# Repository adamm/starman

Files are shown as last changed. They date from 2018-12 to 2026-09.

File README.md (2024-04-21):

# Starman Christmas Tree Topper

Disclaimer: This work is a *work-in-progress*.  While this project is still
under active development, version 2.1 was released _December 1st, 2022_.
What you see here is code that is largely incomplete, buggy, crashes,
and could catch fire. The PCB board is largely inefficient, expensive,
broken, and could catch fire.

Version 1 of the star is a POC I created a few years ago which was literally
a 3d-printed star with 24 LEDs hot-glued onto it, driven by a LED PWM
module from Adafruit, 3 PWM channels for audio, running from an Arduino Uno.

Version 2 is a complete redesign for 2022, including a custom PCB, 144
LEDs, 235 components, ESP32-S3 MCU, esp-idf framework, and WiFi/Bluetooth
support.  Audio is driven by 4 PWM channels, featuring a volume control and
a class-D amplifier.

Version 2.1 includes over-the-air firmware updates. I plan on releasing
new themes and songs every Holiday season. 

As of December 2023, there are **7 themes** and **81 arranged songs**.

> [!NOTE]
> I'll be demoing the Starman project, as well demoing its build process at [Calgary Maker Faire, May 4 & 5 2024](https://calgary.makerfaire.com/).
> Come talk to me if you are interested in purchasing a pre-built Starman for Christmas 2024!

You can see v2 in action here: https://www.youtube.com/watch?v=h6fquYPDars

Starman v2 Christmas Tree Star (https://www.youtube.com/watch?v=h6fquYPDars)

The PCB is created using KiCad:

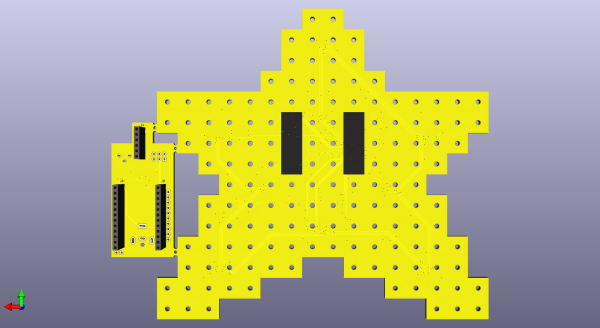
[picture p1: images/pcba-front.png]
Starman v2 PCB front

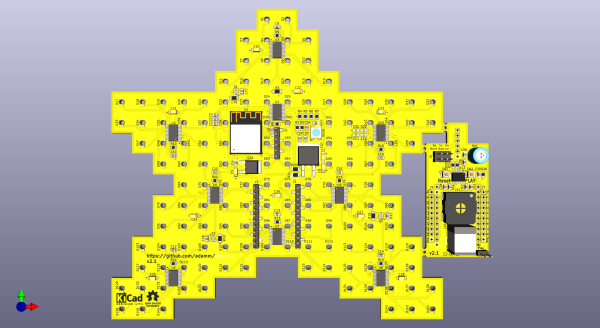
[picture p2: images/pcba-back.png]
Starman v2 PCB back


The sound module connects to the spine of the star through 20mm pin socket
risers.  Finally, a 3d-printed mount secures the display to the christmas
tree's top branch via the risers:

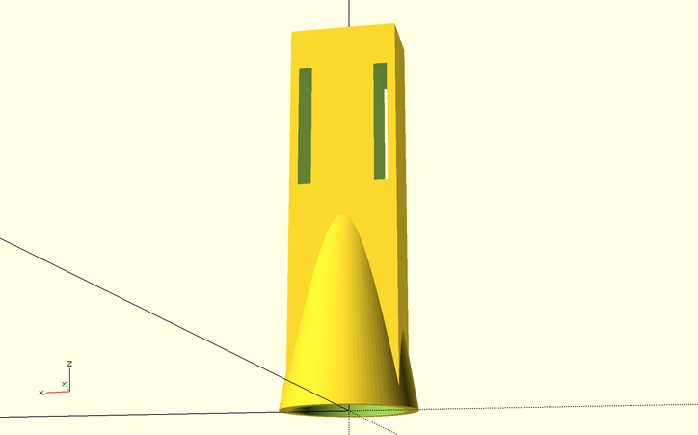
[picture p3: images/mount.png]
3D-printed mount


I plan on producing 10 units for friends and family for Christmas 2022.
Right now the costs are too high to mass produce, so perhaps sometime in
2023 I can simplify the design and cut costs for general orders.

## HOW TO PLAY

- Press the button to start the game.
- Start the game with three lives at level 1 (overworld).  If you lose all lives, it's game over.
- There is a 50% chance you will complete each level.  If you do, you move onto next level.  If not, you die and need to retry.
  - Death can occur randomly within the level.
  - Press the button again to start the next level, or retry the same level.
- There is a 40% chance you'll get a star.
  - Stars can occur randomly within the level.
  - Stars do not negate death (ie, falling into a pit).
- There is a 25% chance you'll get a 1-up, resulting in an extra life.
- If you make it to level 4 (castle) and complete it, there is a 25% chance the princess will be there and the game is over.

## Installation

1. Install Starman at the top of your tree, or on your desk, shelf, or wall.
2. Connect the play button remote cable to the play button port.  Hide the play button in your tree, desk, shelf, or wall.
3. Power it on.
4. (Optiona) Connect to your wifi network (see below) to configure the brightness and theme.
5. Press the physical play button, or press Play on the Starman web app

### Wifi Setup

1. Power on the Starman
2. Watch for a "starman_######" access point, and connect to it.
3. Search for your home Wifi, and enter the credentials
  - Starman can only connect to 2.4Ghz/WPA2 endpoints
4. Once connected, wait for your IP address to scroll past the screen
5. Open the IP address in your web browser
  - You can now use this site to play Starman directly, and to access the internal API.

If you ever want to factory reset Starman, follow this procedure:
1. Press and hold *Play* button
2. Press and release *Reset* button
3. Release *Play* button
Starman will forget about its current wifi configuration, theme, and configuration. Follow the Wifi Setup instructions above to set it back up again.

## TODO

- [X] Finalize PCB design
- [X] Play music
- [X] Implement game logic
- [X] Unique light pattern per music song/state
- [X] Flash lights in sequence with music
- [X] GPIO play button
- [X] Show simple text messages
- [X] WiFi onboarding process
- [X] Over-the-air firmware updates
- [X] WiFi play button
- [X] HTTP REST API to push text, play sound
- [X] Brightness control
- [X] Selectable themes
- [ ] Document the REST API
- [ ] Upgrade the speaker from 800mW to 1.5W for more power
- [ ] Debug the RC filter to reduce distortion

## Known Issues

- v2.1 PCB has a label that says it supports 7 to 12 volts power.  *WARNING: only 6-7V is actually supported in v2.1 hardware. __Do not connect more than 7 volts!__*
- Only 2.4Gz WPA2 wifi is supported   (Cannot connect to 5Gz or WPA Enterprise)
- Sound gets distorted at high volume levels.
- It can take a long time after startup to get an IP address and start
  the web service
- Even though wifi and the web service are online and functioning, the
  index.html sometimes takes a long time to load
- Sometimes the device spontaneously resets if wifi connection is not
  stable or strong enough
- Some songs are way too long. (>60s)
- Some songs end way too early (<3s) with a "course completed" event.

## Milestones

2022-09-01
- PCB layout identified and key components selected

2022-09-25
- Components ordered and footprints verified

2022-09-27
- Upgrade from ESP32-S2 to ESP32-S3

2022-09-29
- PCB design delivered for production

2022-10-09
- Complete migration of core game logic from Arduino version (v1) to esp-idf version (v2)

2022-10-29
- Framework for connecting to wifi / performing OTA updates

2022-11-02
- Framework for showing basic text messages, like "Game Over", "Connect to Wifi", "Firmware Update in progress", etc

2022-11-27
- Manufacturing is complete for 10 units for friends and family.

## Key Components

- ESP32-S3-Mini module

- 9x LED1642GW drivers

- 144 OSRAM LY P47 2mm LEDs

- PAM8302A amplifer

- 239 total components (35 unique)

- Translate MIDI to Playtune C array
  - https://github.com/lenshustek/miditones

## Build Dependencies

- See [BUILDING](BUILDING.md) document.

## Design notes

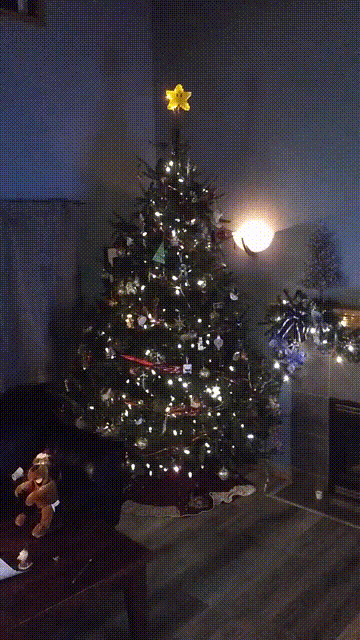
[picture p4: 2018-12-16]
images/starman-tree.gif

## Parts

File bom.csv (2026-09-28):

Refs | Value | Footprint | Qty | DNP
C1, C2, C5, C6, C40 | 10uF | Capacitor_SMD:C_0805_2012Metric,Capacitor_Tantalum_SMD:CP_EIA-3216-10_Kemet-I | 5
C3, C4, C8-C19, C35, C36, C39 | 1uF | Capacitor_SMD:C_0805_2012Metric | 17
C7, C30 | 22uF | Capacitor_SMD:C_0805_2012Metric,Capacitor_Tantalum_SMD:CP_EIA-3216-10_Kemet-I | 2
C20-C28 | 47uF | Capacitor_Tantalum_SMD:CP_EIA-3216-10_Kemet-I | 9
C29, C34 | 0.1uF | Capacitor_SMD:C_0805_2012Metric | 2
C33 | 1uF nc | Capacitor_SMD:C_0805_2012Metric | 1
C37, C38 | 220pF | Capacitor_SMD:C_0805_2012Metric | 2
D1-D144 | LED | starman:LED_Osram_Lx_P47F_D2mm_ReverseMount | 144
D145 | WS2812B nc | LED_SMD:LED_WS2812B_PLCC4_5.0x5.0mm_P3.2mm | 1
FB1, FB2 | FerriteBead | Capacitor_SMD:C_0805_2012Metric | 2
J1-J3 | M20-8771246 | Connector_PinHeader_2.54mm:PinHeader_1x06_P2.54mm_Vertical_SMD_Pin1Right,Connector_PinHeader_2.54mm:PinHeader_1x12_P2.54mm_Vertical_SMD_Pin1Right | 3
J4 | ESW-106-44-T-S | Connector_PinSocket_2.54mm:PinSocket_1x06_P2.54mm_Vertical | 1
J5 | PH2-06-UA | Connector_PinHeader_2.54mm:PinHeader_2x03_P2.54mm_Vertical | 1
J6, J8 | ESW-112-44-T-S | Connector_PinSocket_2.54mm:PinSocket_1x12_P2.54mm_Vertical | 2
J7, J9 | Conn_01x10 | Connector_PinHeader_2.54mm:PinHeader_1x10_P2.54mm_Vertical | 2
J10 | PJ-063AH | Connector_BarrelJack:BarrelJack_CUI_PJ-063AH_Horizontal | 1
J11, J12 | Conn_02x01 | Connector_PinHeader_2.54mm:PinHeader_1x02_P2.54mm_Vertical | 2
LS1 | SMS-1508MS-HT-R | starman:SPKR_SMS-1508MS-HT-R | 1
R1, R2 | 10k | Resistor_SMD:R_0805_2012Metric | 2
R3, R17-R19 | 500k | Resistor_SMD:R_1206_3216Metric | 4
R4-R7 | 75 | Resistor_SMD:R_0805_2012Metric | 4
R8-R16 | 11k | Resistor_SMD:R_0805_2012Metric | 9
R20 | 750 | Resistor_SMD:R_1206_3216Metric | 1
R21 | 250 | Resistor_SMD:R_1206_3216Metric | 1
R24, R25 | 100 | Resistor_SMD:R_0805_2012Metric | 2
R26 | 1k | Resistor_SMD:R_0805_2012Metric | 1
RV1 | 20k | Potentiometer_THT:Potentiometer_Bourns_3339P_Vertical | 1
SW1, SW2 | PTS810 SJM 250 SMTR LFS | Button_Switch_SMD:SW_SPST_PTS810 | 2
U1 | ESP32-S3-MINI-1 | Espressif:ESP32-S3-MINI-1 | 1
U2-U10 | LED1642GWTTR | Package_SO:TSSOP-24_4.4x7.8mm_P0.65mm | 9
U11 | AZ1084CS2-ADJ | Package_TO_SOT_SMD:TO-263-2 | 1
U12 | BA33BC0FP-E2 | Package_TO_SOT_SMD:TO-252-2 | 1
U13 | PAM8302AAS | Package_SO:SOP-8_3.9x4.9mm_P1.27mm | 1
X1-X3 | ECS-2333-300 | Oscillator:Oscillator_SMD_ECS_2520MV-xxx-xx-4Pin_2.5x2.0mm | 3

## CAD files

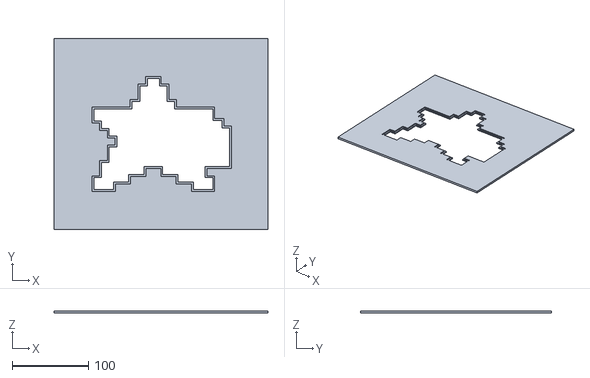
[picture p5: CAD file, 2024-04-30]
mount/stencil.stl
280.0 x 250.0 x 3.00

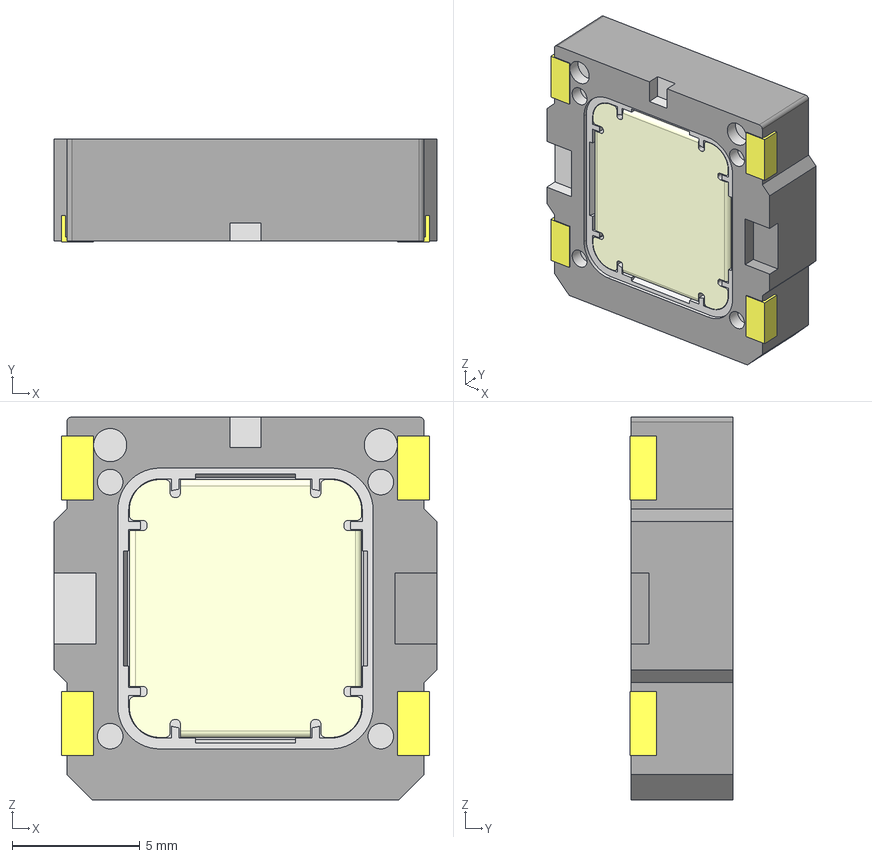
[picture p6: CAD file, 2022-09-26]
pcb/3d/SMS-1508MS-HT-R.step
15.0 x 4.05 x 15.0 mm

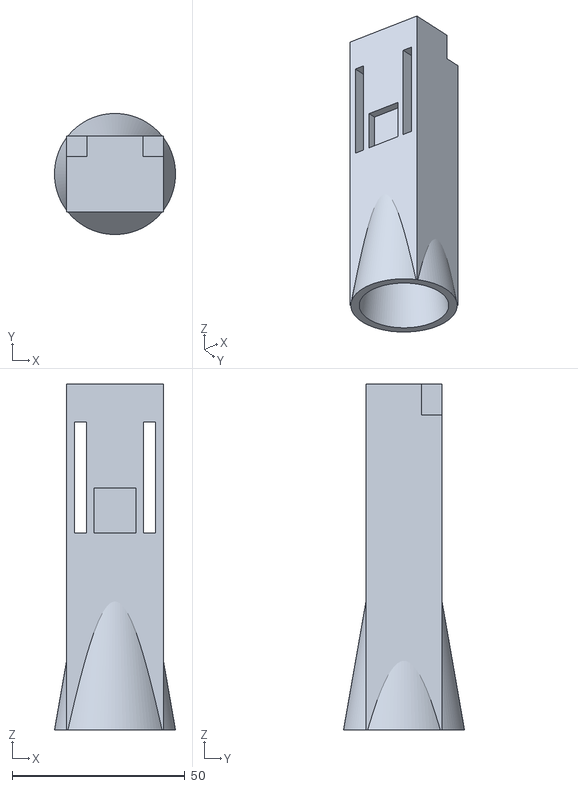
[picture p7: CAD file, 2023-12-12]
mount/mount.stl
35.0 x 35.0 x 100.0

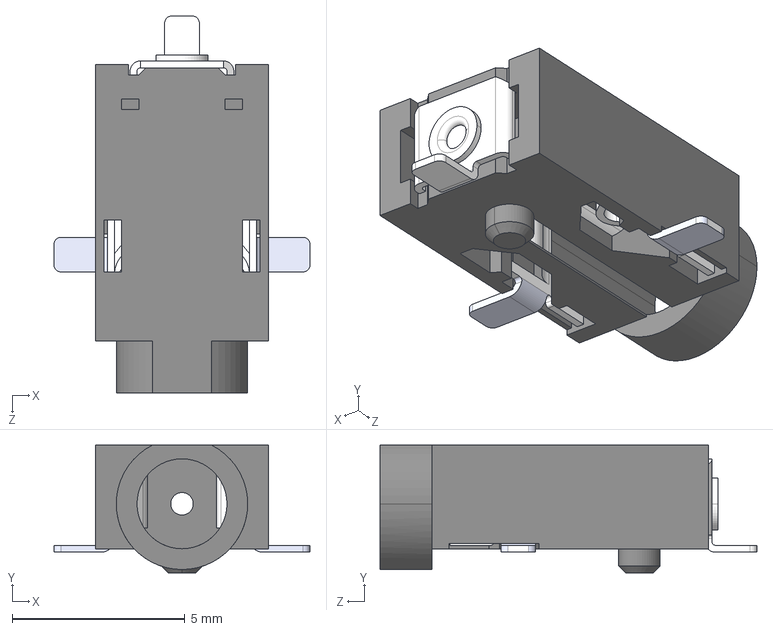
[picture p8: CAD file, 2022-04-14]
pcb/3d/CUI_DEVICES_PJ-040-SMT-TR.step
7.40 x 3.70 x 10.9 mm

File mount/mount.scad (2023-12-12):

/*
   Copyright 2022 Adam McDaniel

   Licensed under the Apache License, Version 2.0 (the "License");
   you may not use this file except in compliance with the License.
   You may obtain a copy of the License at

       http://www.apache.org/licenses/LICENSE-2.0

   Unless required by applicable law or agreed to in writing, software
   distributed under the License is distributed on an "AS IS" BASIS,
   WITHOUT WARRANTIES OR CONDITIONS OF ANY KIND, either express or implied.
   See the License for the specific language governing permissions and
   limitations under the License.
*/

body_w = 28;
body_l = 22;
body_h = 100;
body_x = -(body_w / 2);
body_y = -(body_l / 2);
body_z = 0;

// How far below the top of the body will the socket and treebranch reach?
body_socket_delta = 11;
body_treebranch_delta = 10;

socket_w = 3.5;
socket_l = body_l + 5;
socket_h = 32;

socket_left_x = -8.25 - socket_w;
socket_left_y = -(socket_l / 2);
socket_left_z = body_h - socket_h - body_socket_delta;

socket_right_x = 8.25;
socket_right_y = -(socket_l / 2);
socket_right_z = body_h - socket_h - body_socket_delta;

tree_cylinder_x = 0;
tree_cylinder_y = 0;
tree_cylinder_z = body_h - 50;
tree_cylinder_r = 7;
tree_cylinder_h = 50;

tree_cone_x = 0;
tree_cone_y = 0;
tree_cone_z = -0.01;
tree_cone_r = 7;
tree_cone_h = 60;

ldo_notch_w = 6;
ldo_notch_h = 9;
ldo_notch_l = 6;
ldo_notch_x1 = body_w/2 - ldo_notch_w + 0.1;
ldo_notch_x2 = -body_w/2 - 0.1;
ldo_notch_y = body_l/2 - ldo_notch_w + 0.1;
ldo_notch_z = body_h - ldo_notch_h + 0.1;

j10_notch_w = 12;
j10_notch_h = 13;
j10_notch_l = 3;
j10_notch_x = -j10_notch_w/2;
j10_notch_y = -body_l/2 - 0.1;
j10_notch_z = socket_left_z;

$fn = 100;

module mount_3d() {

    difference() {
        union() {
            translate([body_x, body_y, body_z])
                cube([body_w, body_l, body_h]);

            translate([tree_cone_x, tree_cone_y, tree_cone_z])
                cylinder(r=tree_cone_r, h=tree_cone_h, d1=35);
        }

        translate([socket_left_x, socket_left_y, socket_left_z])
            cube([socket_w, socket_l, socket_h]);

        translate([socket_right_x, socket_right_y, socket_right_z])
            cube([socket_w, socket_l, socket_h]);

        translate([ldo_notch_x1, ldo_notch_y, ldo_notch_z])
            cube([ldo_notch_w, ldo_notch_l, ldo_notch_h]);

        translate([ldo_notch_x2, ldo_notch_y, ldo_notch_z])
            cube([ldo_notch_w, ldo_notch_l, ldo_notch_h]);

        translate([j10_notch_x, j10_notch_y, j10_notch_z])
            cube([j10_notch_w, j10_notch_l, j10_notch_h]);

        translate([tree_cylinder_x, tree_cylinder_y, tree_cylinder_z-2])
            cylinder(r=tree_cylinder_r, h=tree_cylinder_h);

        translate([tree_cone_x, tree_cone_y, tree_cone_z-2])
            cylinder(r=tree_cone_r, h=tree_cone_h, d1=30);

    }
}


mount_3d();

// vim:syntax=c

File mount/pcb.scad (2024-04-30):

$fn = 100;
pcb_w = 151;
pcb_l = 30.5;
pcb_h = 2.2;

module pcb(draw_holes=true) {
    //translate([0, 0, -pcb_h/2])
    //difference() {
        linear_extrude(height=pcb_h) {
            // Add 0.3mm to all ends to better align with
            // 3d printer tolerance
            offset(delta=+0.3) {
                polygon(points=[
                // left side
                [0,0],[0,20],[10,20],[10,40],
                [20,40],[20,60],[30,60],[30,70],
                [20,70],[20,80],[10,80],[10,90],[0,90],
                [0,110],[50,110],[50,120],[60,120],
                [60,140],[70,140],[70,150],[90,150],
                // Top right
                [90,140],[100,140],[100,120],[110,120],
                [110,110],[160,110],
                // Expansion module
                [160,95],[172,95],[172,85],[182,85],[182,30],
                // bottom right
                [150,30],[150,20],[160,20],[160,0],
                // Bottom
                [130,0],[130,10],[110,10],[110,20],
                [90,20],[90,30],[70,30],[70,20],[50,20],
                [50,10],[30,10],[30,0]]);
            }
        }
    //}
}

//rotate([90, 0, 90]) {
//    union() {
//        pcb(true);
//    }
//}

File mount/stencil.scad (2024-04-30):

include <pcb.scad>;


board_w = 280;
board_h = 3.0;
board_l = 250;
board_x = -50;
board_y = -50;
board_z = 0.01;

stencil_w = 240;
stencil_h = 3;
stencil_l = 210;
stencil_x = -30;
stencil_y = -30;
stencil_z = 3;

module negative_pcb(x, y, z) {
    translate([x, y, z+1.4])
        pcb(false);
    translate([x, y, z])
        linear_extrude(height=board_h+4)
            offset(delta=-2.5)
                projection(cut=true)
                    pcb(false);
}

module board() {
    difference() {
        translate([board_x, board_y, board_z])
            cube([board_w, board_l, board_h]);
        //translate([stencil_x, stencil_y, stencil_z])
            //cube([stencil_w, stencil_l, stencil_h]);
        negative_pcb(0, 0, 0);
    }
}

board();

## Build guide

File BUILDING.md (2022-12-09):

# BUILDING

This doc describes building the source code, not building your own Starman :)
Except for Step 1, the instructions here are not specific to Starman and can be
used for any "esp-idf"-based project.

> While the Starman hardware is Arduino-compabile, the codebase is not written
> using the Arduino toolchain.  If you want to use the hardware as an arbitrary
> Arduino device, feel free, but to access the lights and sound you'll have to
> write your own port :)

## 1. Solder 2x3 headers onto J5

The back module pops off, but it's pretty stiff.  Take care not to damage any
of the components.  This will allow you access to the back to solder on the
headers, if they're not there already.

## 2. Get an [ESP-Prog](https://espressif-docs.readthedocs-hosted.com/projects/espressif-esp-iot-solution/en/latest/hw-reference/ESP-Prog_guide.html) and cables to connect to J5

Be sure to match up pins with the ESP-Prog's 2x3
[communication interface](https://espressif-docs.readthedocs-hosted.com/projects/espressif-esp-iot-solution/en/latest/hw-reference/ESP-Prog_guide.html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).
A ribbon cable [like this one](https://www.amazon.ca/CablesOnline-12-inch-2-54mm-Pitch-Female-FR-0612/dp/B078LM31J9)
is most convenient.

Alternatively, you can get away with not using an ESP-Prog and instead use any
FTDI USB->Serial adapter, [like this one](https://www.sparkfun.com/products/9717),
just be sure it's 3.3V logic level.  Also, you won't have convenient access to
trigger the boot and reset pins automatically.  You'll have to manually touch
those to ground to reset into bootloader mode and upload new code.

Be sure to only connect your cable to the TX, RX, and Gnd pins on J5.  The
transmit/receive is relative to the Starman MCU, so you may need to
connect the TX pin to your cable's RX port, and vice versa.

## 3. [Download and install the FDTI driver](https://ftdichip.com/drivers/vcp-drivers/)

If you have an ESP-Prog or other FTDI USB->Serial device or cable, download
and install the FTDI drivers [here](https://ftdichip.com/drivers/vcp-drivers/).
If you have a non-FTDI USB->Serial device, you'll need to follow its instructions.

## 4. [Download and install the esp-idf toolchain](https://docs.espressif.com/projects/esp-idf/en/latest/esp32/get-started/index.html#installation)

## 5. Clone this repository

The codebase lives in the main/ directory, but be sure to run all the
following commands in the root of the cloned repository.

## 6. Build, Flash, Monitor the project

If you're using an IDE with the [Eclipse plugin](https://github.com/espressif/idf-eclipse-plugin/blob/master/README.md)
or [VSCode extension](https://github.com/espressif/vscode-esp-idf-extension/blob/master/docs/tutorial/install.md),
follow those instructions.  If you using the command-line follow these steps frim the firmware/ directory:

1. `idf.py set-target esp32s3` to prepare the build environment.  (You only need to do this once.)

2. `idf.py build` to compile the project.

3. `idf.py flash` to actually upload the compiled binary.

To upload your code you need to be in bootloader mode.  The ESP-Prog will
take care of this for you, but if you used your own cable or FTDI device,
you'll have to manually enter bootloader mode.  To do this, connect J5
"Boot" pin to "Gnd", press the Reset button, then disconnect the "Boot" pin.
Run `idf.py flash` normally.  After flashing is complete you need to press
"Reset" again for normal operations.

4. `idf.py monitor` to open up a serial port to monitor the logs of the device.

You can combine all three steps into one command `idf.py build flash monitor`
for convenience.

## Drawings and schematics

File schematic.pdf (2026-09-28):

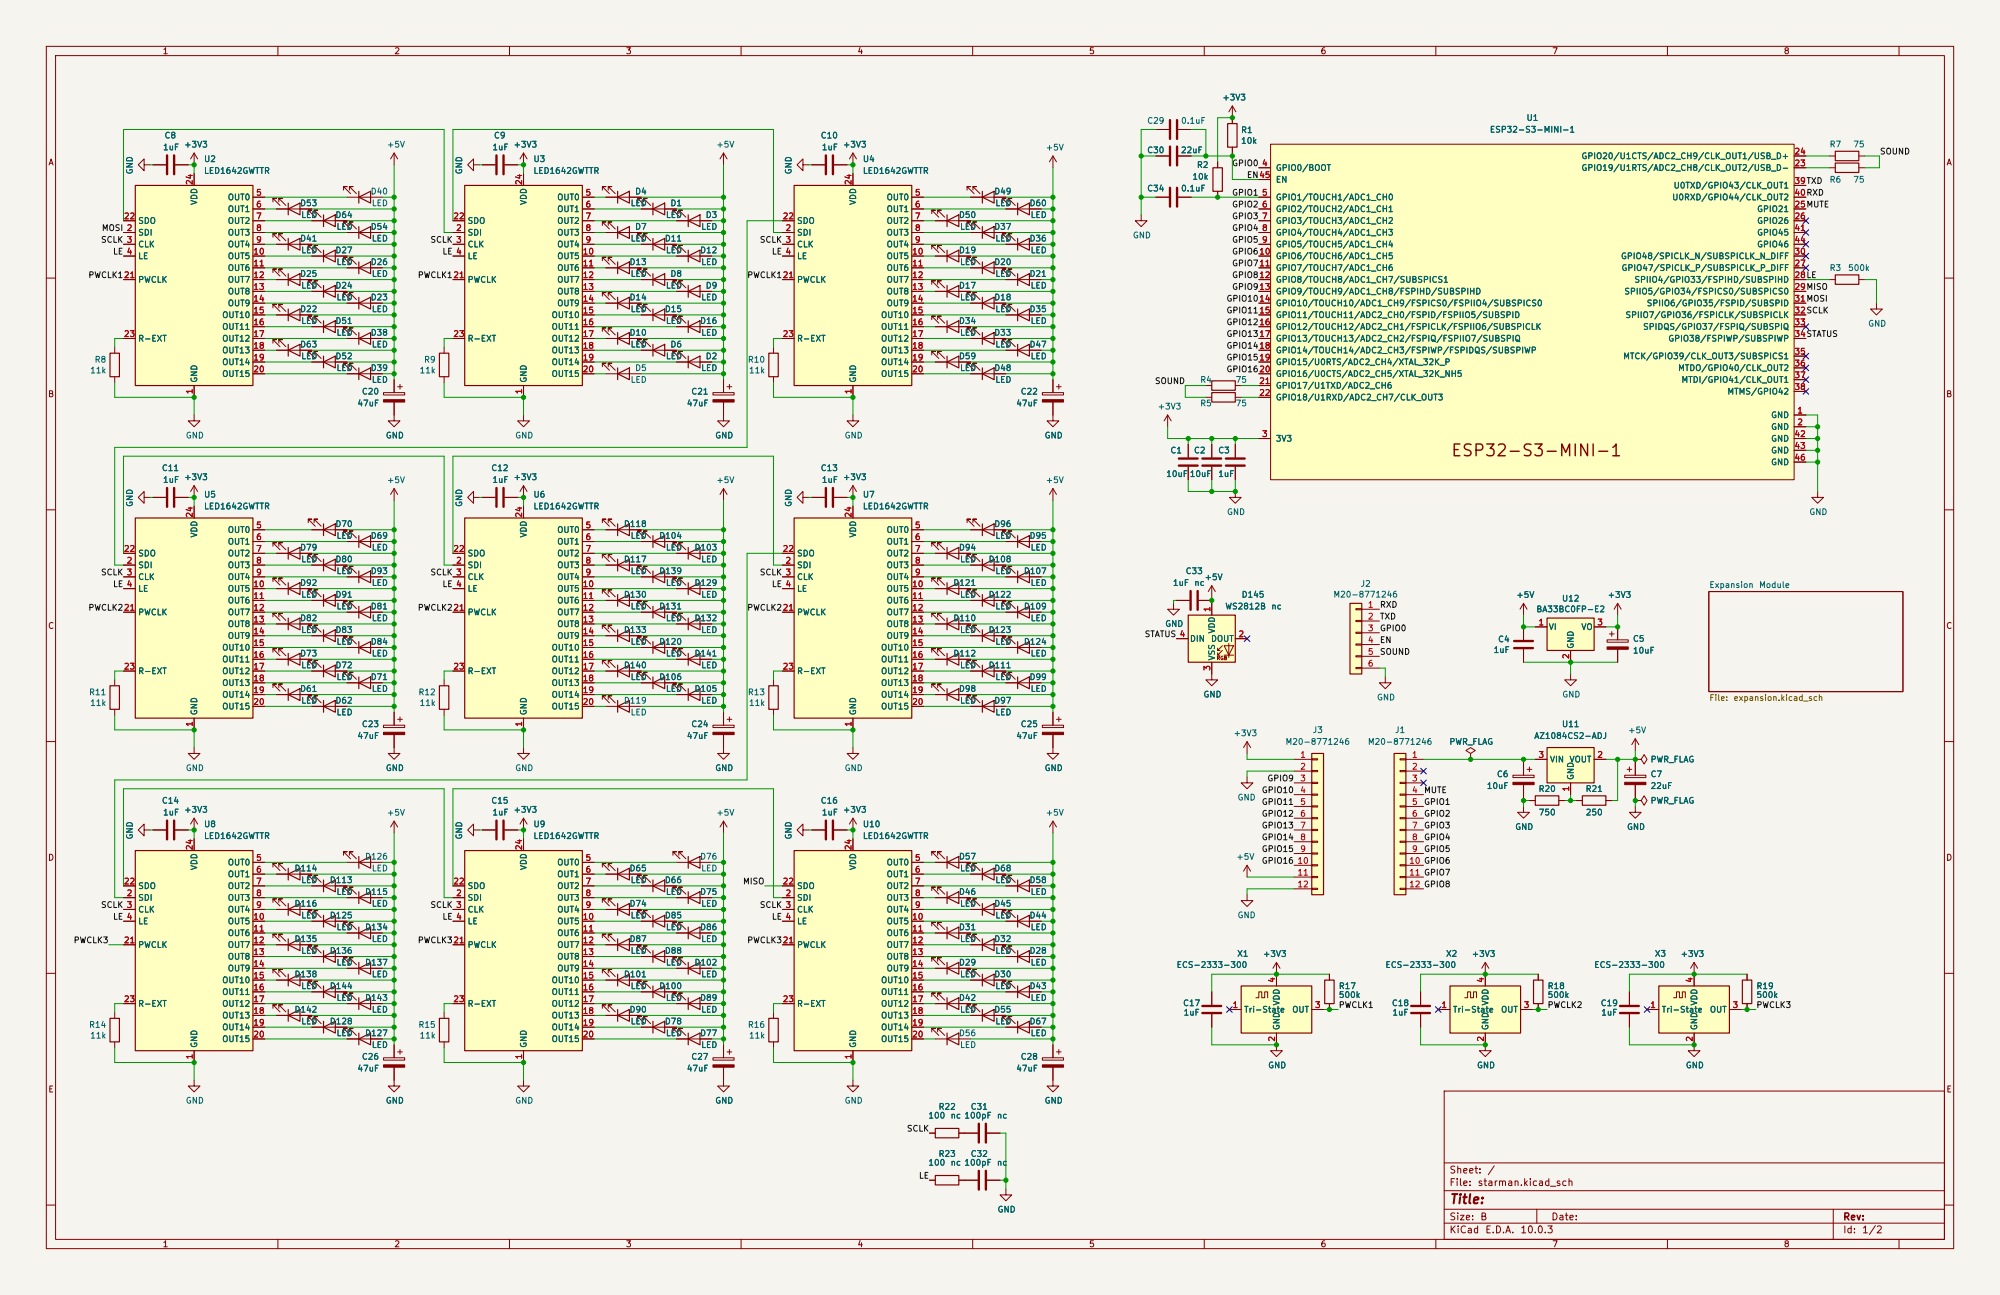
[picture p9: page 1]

SOUND MISO MOSI STATUS

Size: B | Rev:
KiCad E.D.A. 10.0.3 | Id: 1/2

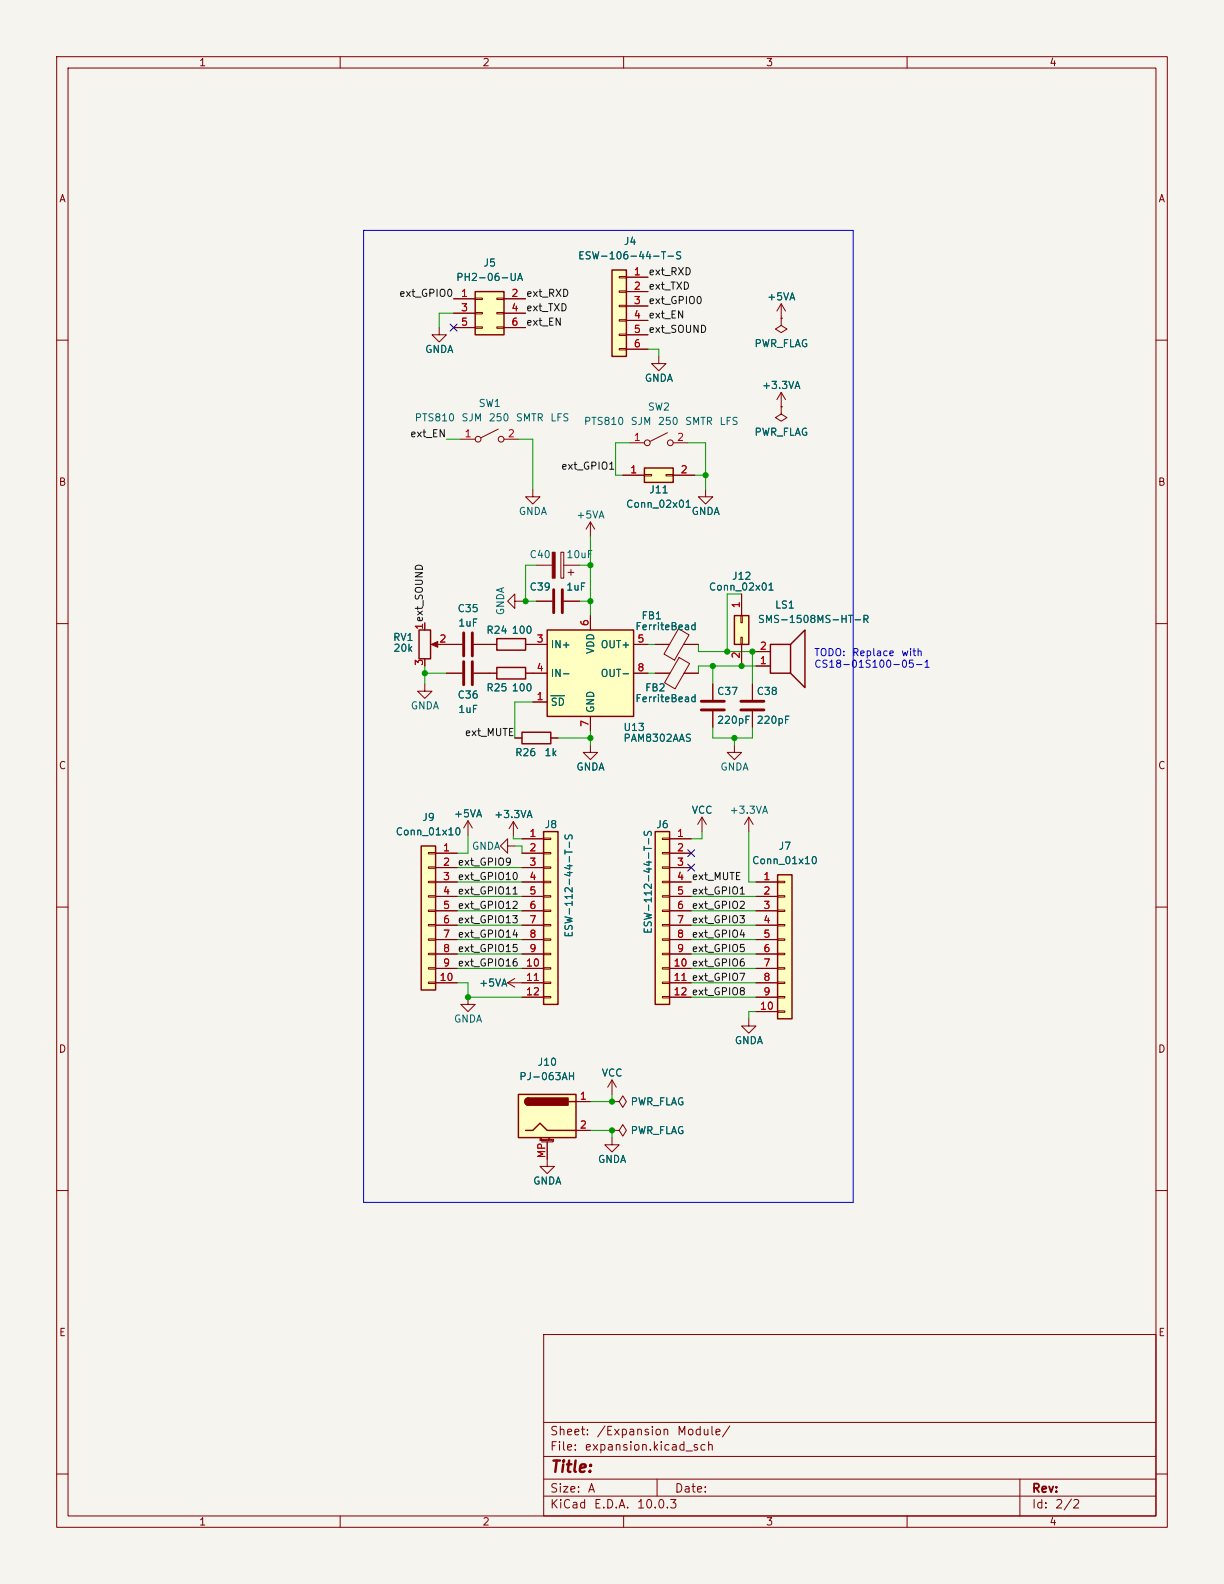
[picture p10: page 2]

Size: A | Rev:
KiCad E.D.A. 10.0.3 | Id: 2/2

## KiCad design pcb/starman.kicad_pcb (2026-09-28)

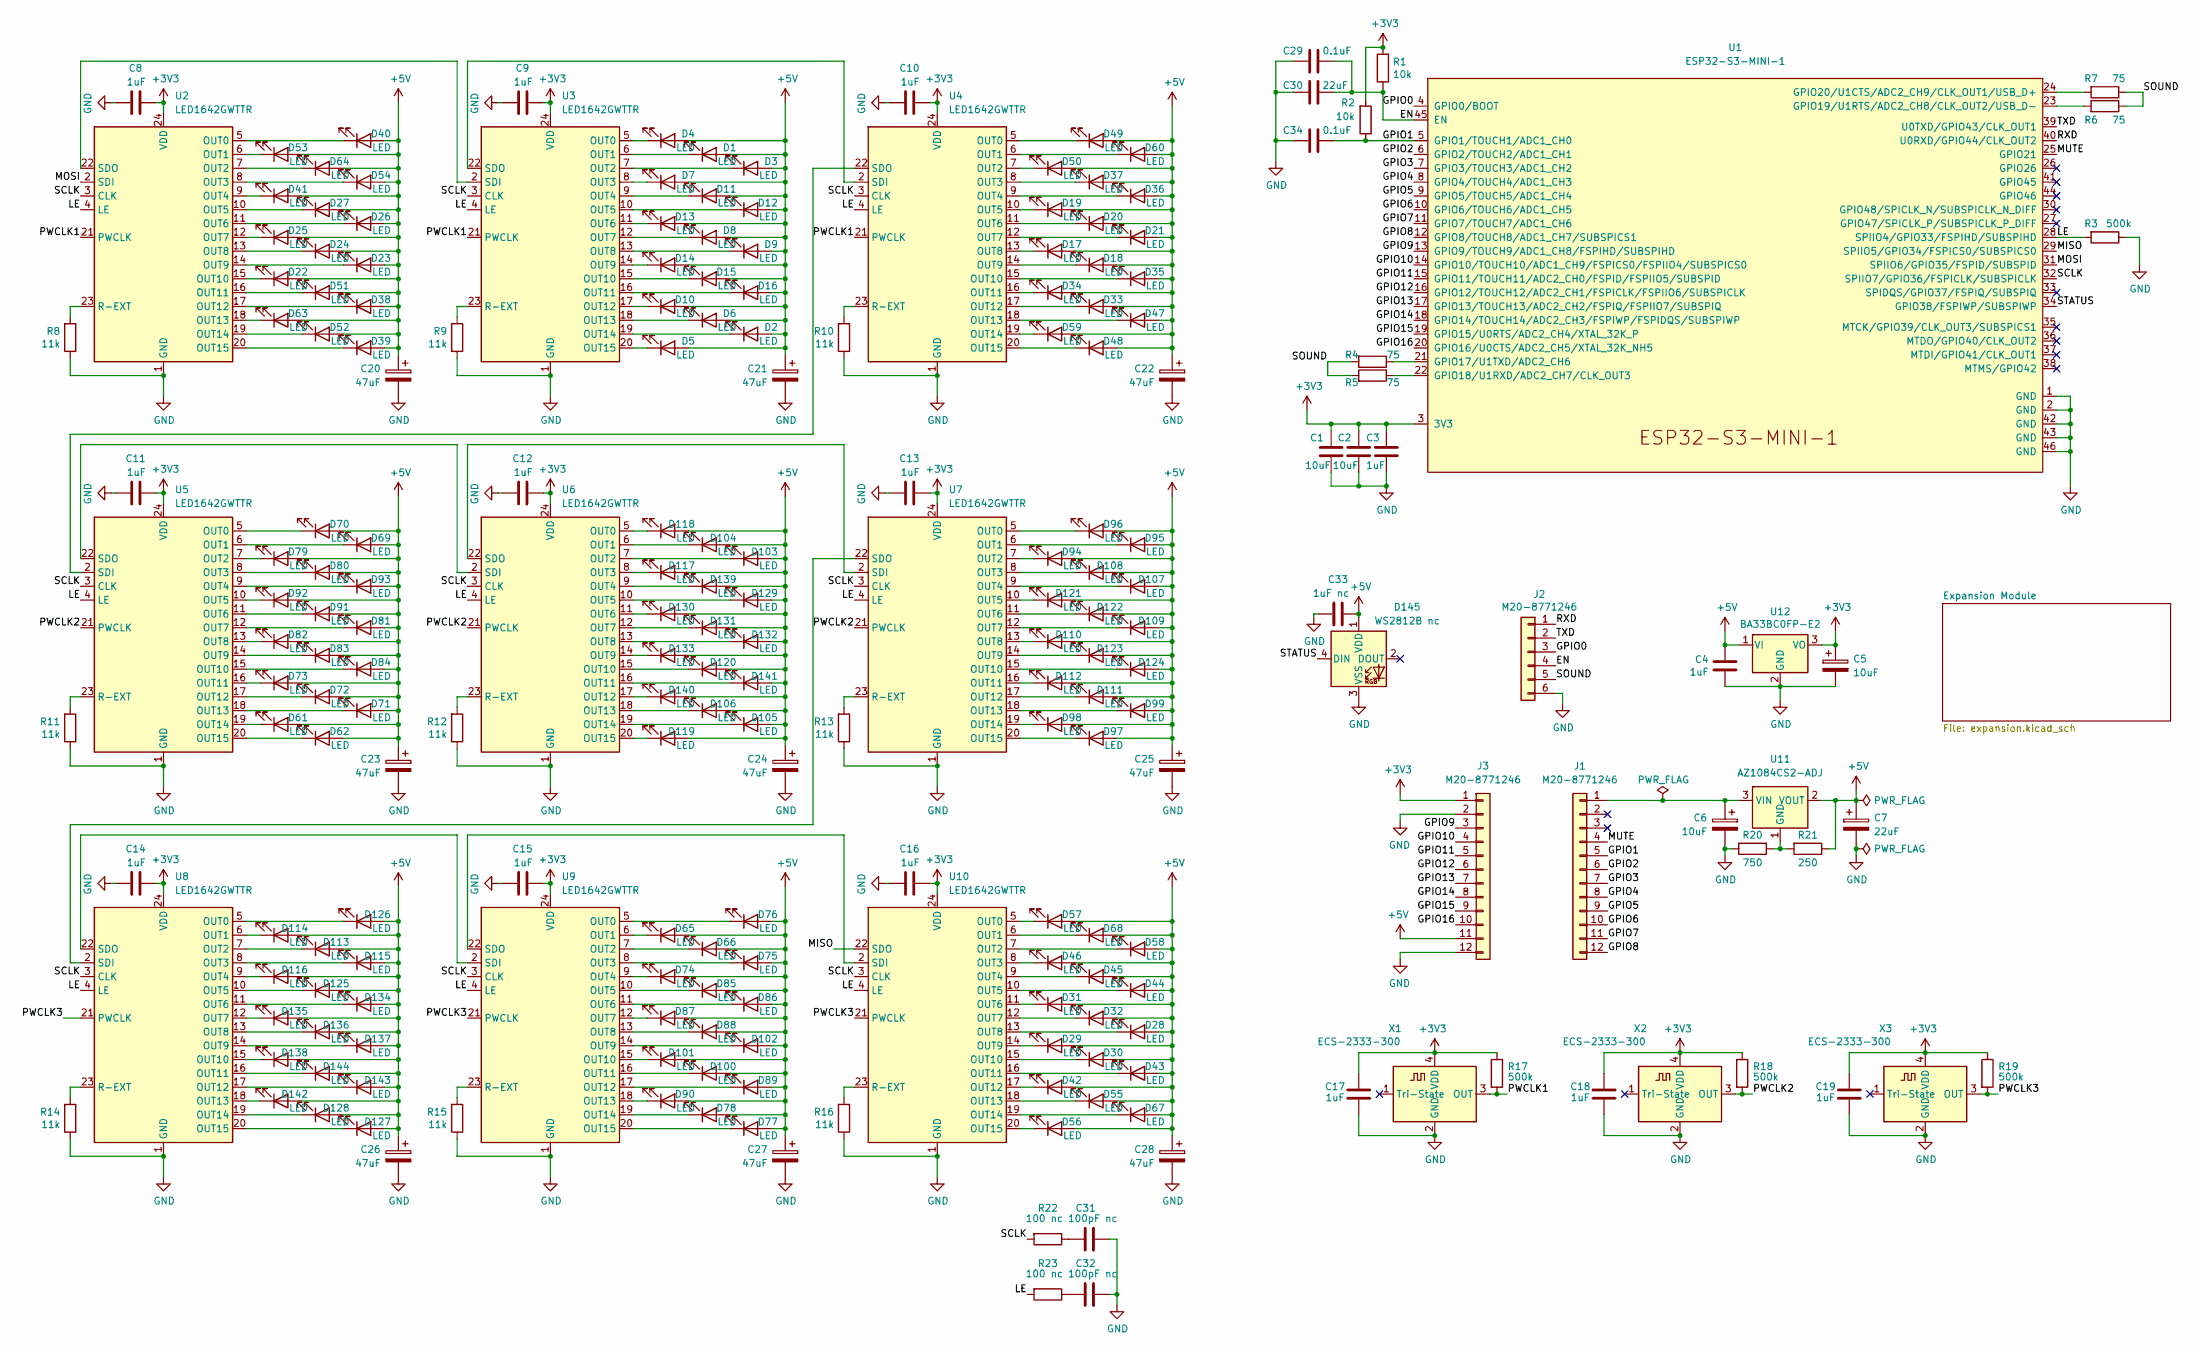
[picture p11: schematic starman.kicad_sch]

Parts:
C1, C2: 10uF; C_0805_2012Metric
C3, C4, C8, C9, C10, C11, C12, C13, C14, C15, C16, C17, C18, C19: 1uF; C_0805_2012Metric
C5, C6: 10uF; CP_EIA-3216-10_Kemet-I
C7: 22uF; CP_EIA-3216-10_Kemet-I
C20, C21, C22, C23, C24, C25, C26, C27, C28: 47uF; CP_EIA-3216-10_Kemet-I
C29, C34: 0.1uF; C_0805_2012Metric
C30: 22uF; C_0805_2012Metric
C31, C32: 100pF nc; C_0805_2012Metric
C33: 1uF nc; C_0805_2012Metric
D1, D2, D3, D4, D5, D6, D7, D8, D9, D10, D11, D12, D13, D14, D15, D16, D17, D18, D19, D20, D21, D22, D23, D24, D25, D26, D27, D28, D29, D30, D31, D32, D33, D34, D35, D36, D37, D38, D39, D40, D41, D42, D43, D44, D45, D46, D47, D48, D49, D50, D51, D52, D53, D54, D55, D56, D57, D58, D59, D60, D61, D62, D63, D64, D65, D66, D67, D68, D69, D70, D71, D72, D73, D74, D75, D76, D77, D78, D79, D80, D81, D82, D83, D84, D85, D86, D87, D88, D89, D90, D91, D92, D93, D94, D95, D96, D97, D98, D99, D100, D101, D102, D103, D104, D105, D106, D107, D108, D109, D110, D111, D112, D113, D114, D115, D116, D117, D118, D119, D120, D121, D122, D123, D124, D125, D126, D127, D128, D129, D130, D131, D132, D133, D134, D135, D136, D137, D138, D139, D140, D141, D142, D143, D144: LED; LED_Osram_Lx_P47F_D2mm_ReverseMount
D145: WS2812B nc; LED_WS2812B_PLCC4_5.0x5.0mm_P3.2mm
J1, J3: M20-8771246; PinHeader_1x12_P2.54mm_Vertical_SMD_Pin1Right
J2: M20-8771246; PinHeader_1x06_P2.54mm_Vertical_SMD_Pin1Right
R1, R2: 10k; R_0805_2012Metric
R3, R17, R18, R19: 500k; R_1206_3216Metric
R4, R5, R6, R7: 75; R_0805_2012Metric
R8, R9, R10, R11, R12, R13, R14, R15, R16: 11k; R_0805_2012Metric
R20: 750; R_1206_3216Metric
R21: 250; R_1206_3216Metric
R22, R23: 100 nc; R_0805_2012Metric
U1: ESP32-S3-MINI-1
U2, U3, U4, U5, U6, U7, U8, U9, U10: LED1642GWTTR; TSSOP-24_4.4x7.8mm_P0.65mm
U11: AZ1084CS2-ADJ; TO-263-2
U12: BA33BC0FP-E2; TO-252-2
X1, X2, X3: ECS-2333-300; Oscillator_SMD_ECS_2520MV-xxx-xx-4Pin_2.5x2.0mm

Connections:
+3V3: C1.2, C2.2, C3.2, C5.1, C8.1, C9.1, C10.1, C11.1, C12.1, C13.1, C14.1, C15.1, C16.1, C17.2, C18.2, C19.2, J3.1, R1.2, R2.2, R17.1, R18.1, R19.1, U1.3 (3V3), U2.24 (VDD), U3.24 (VDD), U4.24 (VDD), U5.24 (VDD), U6.24 (VDD), U7.24 (VDD), U8.24 (VDD), U9.24 (VDD), U10.24 (VDD), U12.3 (VO), X1.4 (VDD), X2.4 (VDD), X3.4 (VDD)
+5V: C4.2, C7.1, C20.1, C21.1, C22.1, C23.1, C24.1, C25.1, C26.1, C27.1, C28.1, C33.1, D1.2 (A), D2.2 (A), D3.2 (A), D4.2 (A), D5.2 (A), D6.2 (A), D7.2 (A), D8.2 (A), D9.2 (A), D10.2 (A), D11.2 (A), D12.2 (A), D13.2 (A), D14.2 (A), D15.2 (A), D16.2 (A), D17.2 (A), D18.2 (A), D19.2 (A), D20.2 (A), D21.2 (A), D22.2 (A), D23.2 (A), D24.2 (A), D25.2 (A), D26.2 (A), D27.2 (A), D28.2 (A), D29.2 (A), D30.2 (A), D31.2 (A), D32.2 (A), D33.2 (A), D34.2 (A), D35.2 (A), D36.2 (A), D37.2 (A), D38.2 (A), D39.2 (A), D40.2 (A), D41.2 (A), D42.2 (A), D43.2 (A), D44.2 (A), D45.2 (A), D46.2 (A), D47.2 (A), D48.2 (A), D49.2 (A), D50.2 (A), D51.2 (A), D52.2 (A), D53.2 (A), D54.2 (A), D55.2 (A), D56.2 (A), D57.2 (A), D58.2 (A), D59.2 (A), D60.2 (A), D61.2 (A), D62.2 (A), D63.2 (A), D64.2 (A), D65.2 (A), D66.2 (A), D67.2 (A), D68.2 (A), D69.2 (A), D70.2 (A), D71.2 (A), D72.2 (A), D73.2 (A), D74.2 (A), D75.2 (A), D76.2 (A), D77.2 (A), D78.2 (A), D79.2 (A), D80.2 (A), D81.2 (A), D82.2 (A), D83.2 (A), D84.2 (A), D85.2 (A), D86.2 (A), D87.2 (A), D88.2 (A), D89.2 (A), D90.2 (A), D91.2 (A), D92.2 (A), D93.2 (A), D94.2 (A), D95.2 (A), D96.2 (A), D97.2 (A), D98.2 (A), D99.2 (A), D100.2 (A), D101.2 (A), D102.2 (A), D103.2 (A), D104.2 (A), D105.2 (A), D106.2 (A), D107.2 (A), D108.2 (A), D109.2 (A), D110.2 (A), D111.2 (A), D112.2 (A), D113.2 (A), D114.2 (A), D115.2 (A), D116.2 (A), D117.2 (A), D118.2 (A), D119.2 (A), D120.2 (A), D121.2 (A), D122.2 (A), D123.2 (A), D124.2 (A), D125.2 (A), D126.2 (A), D127.2 (A), D128.2 (A), D129.2 (A), D130.2 (A), D131.2 (A), D132.2 (A), D133.2 (A), D134.2 (A), D135.2 (A), D136.2 (A), D137.2 (A), D138.2 (A), D139.2 (A), D140.2 (A), D141.2 (A), D142.2 (A), D143.2 (A), D144.2 (A), D145.1 (VDD), J3.11, R21.1, U11.2 (VOUT), U12.1 (VI)
/EN: C29.1, C30.1, J2.4, R1.1, U1.45 (EN)
/GPIO0: J2.3, U1.4 (GPIO0/BOOT)
/GPIO1: C34.1, J1.5, R2.1, U1.5 (GPIO1/TOUCH1/ADC1_CH0)
/GPIO2: J1.6, U1.6 (GPIO2/TOUCH2/ADC1_CH1)
/GPIO3: J1.7, U1.7 (GPIO3/TOUCH3/ADC1_CH2)
/GPIO4: J1.8, U1.8 (GPIO4/TOUCH4/ADC1_CH3)
/GPIO5: J1.9, U1.9 (GPIO5/TOUCH5/ADC1_CH4)
/GPIO6: J1.10, U1.10 (GPIO6/TOUCH6/ADC1_CH5)
/GPIO7: J1.11, U1.11 (GPIO7/TOUCH7/ADC1_CH6)
/GPIO8: J1.12, U1.12 (GPIO8/TOUCH8/ADC1_CH7/SUBSPICS1)
/GPIO9: J3.3, U1.13 (GPIO9/TOUCH9/ADC1_CH8/FSPIHD/SUBSPIHD)
/GPIO10: J3.4, U1.14 (GPIO10/TOUCH10/ADC1_CH9/FSPICS0/FSPIIO4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)
/GPIO11: J3.5, U1.15 (GPIO11/TOUCH11/ADC2_CH0/FSPID/FSPIIO5/S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)
/GPIO12: J3.6, U1.16 (GPIO12/TOUCH12/ADC2_CH1/FSPICLK/FSPIIO6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)
/GPIO13: J3.7, U1.17 (GPIO13/TOUCH13/ADC2_CH2/FSPIQ/FSPIIO7/S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)
/GPIO14: J3.8, U1.18 (GPIO14/TOUCH14/ADC2_CH3/FSPIWP/FSPIDQS/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)
/GPIO15: J3.9, U1.19 (GPIO15/U0RTS/ADC2_CH4/XTAL_32K_P)
/GPIO16: J3.10, U1.20 (GPIO16/U0CTS/ADC2_CH5/XTAL_32K_NH5)
/LE: R3.2, R23.2, U1.28 (SPIIO4/GPIO33/FSPIHD/SUBSPIHD), U2.4 (LE), U3.4 (LE), U4.4 (LE), U5.4 (LE), U6.4 (LE), U7.4 (LE), U8.4 (LE), U9.4 (LE), U10.4 (LE)
/MISO: U1.29 (SPIIO5/GPIO34/FSPICS0/SUBSPICS0), U10.22 (SDO)
/MOSI: U1.31 (SPIIO6/GPIO35/FSPID/SUBSPID), U2.2 (SDI)
/MUTE: J1.4, U1.25 (GPIO21)
/PWCLK1: R17.2, U2.21 (PWCLK), U3.21 (PWCLK), U4.21 (PWCLK), X1.3 (OUT)
/PWCLK2: R18.2, U5.21 (PWCLK), U6.21 (PWCLK), U7.21 (PWCLK), X2.3 (OUT)
/PWCLK3: R19.2, U8.21 (PWCLK), U9.21 (PWCLK), U10.21 (PWCLK), X3.3 (OUT)
/RXD: J2.1, U1.40 (U0RXD/GPIO44/CLK_OUT2)
/SCLK: R22.2, U1.32 (SPIIO7/GPIO36/FSPICLK/SUBSPICLK), U2.3 (CLK), U3.3 (CLK), U4.3 (CLK), U5.3 (CLK), U6.3 (CLK), U7.3 (CLK), U8.3 (CLK), U9.3 (CLK), U10.3 (CLK)
/SOUND: J2.5, R4.2, R5.2, R6.1, R7.1
/STATUS: D145.4 (DIN), U1.34 (GPIO38/FSPIWP/SUBSPIWP)
/TXD: J2.2, U1.39 (U0TXD/GPIO43/CLK_OUT1)
GND: C1.1, C2.1, C3.1, C4.1, C5.2, C6.2, C7.2, C8.2, C9.2, C10.2, C11.2, C12.2, C13.2, C14.2, C15.2, C16.2, C17.1, C18.1, C19.1, C20.2, C21.2, C22.2, C23.2, C24.2, C25.2, C26.2, C27.2, C28.2, C29.2, C30.2, C31.1, C32.1, C33.2, C34.2, D145.3 (VSS), J2.6, J3.2, J3.12, R3.1, R8.1, R9.1, R10.1, R11.1, R12.1, R13.1, R14.1, R15.1, R16.1, R20.2, U1.1 (GND), U1.2 (GND), U1.42 (GND), U1.43 (GND), U1.46 (GND), U2.1 (GND), U3.1 (GND), U4.1 (GND), U5.1 (GND), U6.1 (GND), U7.1 (GND), U8.1 (GND), U9.1 (GND), U10.1 (GND), U12.2 (GND), X1.2 (GND), X2.2 (GND), X3.2 (GND)
unnamed: C6.1, J1.1, U11.3 (VIN)
unnamed: C31.2, R22.1
unnamed: C32.2, R23.1
unnamed: D1.1 (K), U3.6 (OUT1)
unnamed: D2.1 (K), U3.19 (OUT14)
unnamed: D3.1 (K), U3.7 (OUT2)
unnamed: D4.1 (K), U3.5 (OUT0)
unnamed: D5.1 (K), U3.20 (OUT15)
unnamed: D6.1 (K), U3.18 (OUT13)
unnamed: D7.1 (K), U3.8 (OUT3)
unnamed: D8.1 (K), U3.12 (OUT7)
unnamed: D9.1 (K), U3.13 (OUT8)
unnamed: D10.1 (K), U3.17 (OUT12)
unnamed: D11.1 (K), U3.9 (OUT4)
unnamed: D12.1 (K), U3.10 (OUT5)
unnamed: D13.1 (K), U3.11 (OUT6)
unnamed: D14.1 (K), U3.14 (OUT9)
unnamed: D15.1 (K), U3.15 (OUT10)
unnamed: D16.1 (K), U3.16 (OUT11)
unnamed: D17.1 (K), U4.13 (OUT8)
unnamed: D18.1 (K), U4.14 (OUT9)
unnamed: D19.1 (K), U4.10 (OUT5)
unnamed: D20.1 (K), U4.11 (OUT6)
unnamed: D21.1 (K), U4.12 (OUT7)
unnamed: D22.1 (K), U2.15 (OUT10)
unnamed: D23.1 (K), U2.14 (OUT9)
unnamed: D24.1 (K), U2.13 (OUT8)
unnamed: D25.1 (K), U2.12 (OUT7)
unnamed: D26.1 (K), U2.11 (OUT6)
unnamed: D27.1 (K), U2.10 (OUT5)
unnamed: D28.1 (K), U10.13 (OUT8)
unnamed: D29.1 (K), U10.14 (OUT9)
unnamed: D30.1 (K), U10.15 (OUT10)
unnamed: D31.1 (K), U10.11 (OUT6)
unnamed: D32.1 (K), U10.12 (OUT7)
unnamed: D33.1 (K), U4.17 (OUT12)
unnamed: D34.1 (K), U4.16 (OUT11)
unnamed: D35.1 (K), U4.15 (OUT10)
unnamed: D36.1 (K), U4.9 (OUT4)
unnamed: D37.1 (K), U4.8 (OUT3)
unnamed: D38.1 (K), U2.17 (OUT12)
unnamed: D39.1 (K), U2.20 (OUT15)
unnamed: D40.1 (K), U2.5 (OUT0)
unnamed: D41.1 (K), U2.9 (OUT4)
unnamed: D42.1 (K), U10.17 (OUT12)
unnamed: D43.1 (K), U10.16 (OUT11)
unnamed: D44.1 (K), U10.10 (OUT5)
unnamed: D45.1 (K), U10.9 (OUT4)
unnamed: D46.1 (K), U10.8 (OUT3)
unnamed: D47.1 (K), U4.18 (OUT13)
unnamed: D48.1 (K), U4.20 (OUT15)
unnamed: D49.1 (K), U4.5 (OUT0)
unnamed: D50.1 (K), U4.7 (OUT2)
unnamed: D51.1 (K), U2.16 (OUT11)
unnamed: D52.1 (K), U2.19 (OUT14)
unnamed: D53.1 (K), U2.6 (OUT1)
unnamed: D54.1 (K), U2.8 (OUT3)
unnamed: D55.1 (K), U10.18 (OUT13)
unnamed: D56.1 (K), U10.20 (OUT15)
unnamed: D57.1 (K), U10.5 (OUT0)
unnamed: D58.1 (K), U10.7 (OUT2)
unnamed: D59.1 (K), U4.19 (OUT14)
unnamed: D60.1 (K), U4.6 (OUT1)
unnamed: D61.1 (K), U5.19 (OUT14)
unnamed: D62.1 (K), U5.20 (OUT15)
unnamed: D63.1 (K), U2.18 (OUT13)
unnamed: D64.1 (K), U2.7 (OUT2)
unnamed: D65.1 (K), U9.6 (OUT1)
unnamed: D66.1 (K), U9.7 (OUT2)
unnamed: D67.1 (K), U10.19 (OUT14)
unnamed: D68.1 (K), U10.6 (OUT1)
unnamed: D69.1 (K), U5.6 (OUT1)
unnamed: D70.1 (K), U5.5 (OUT0)
unnamed: D71.1 (K), U5.18 (OUT13)
unnamed: D72.1 (K), U5.17 (OUT12)
unnamed: D73.1 (K), U5.16 (OUT11)
unnamed: D74.1 (K), U9.9 (OUT4)
unnamed: D75.1 (K), U9.8 (OUT3)
unnamed: D76.1 (K), U9.5 (OUT0)
unnamed: D77.1 (K), U9.20 (OUT15)
unnamed: D78.1 (K), U9.19 (OUT14)
unnamed: D79.1 (K), U5.7 (OUT2)
unnamed: D80.1 (K), U5.8 (OUT3)
unnamed: D81.1 (K), U5.12 (OUT7)
unnamed: D82.1 (K), U5.13 (OUT8)
unnamed: D83.1 (K), U5.14 (OUT9)
unnamed: D84.1 (K), U5.15 (OUT10)
unnamed: D85.1 (K), U9.10 (OUT5)
unnamed: D86.1 (K), U9.11 (OUT6)
unnamed: D87.1 (K), U9.12 (OUT7)
unnamed: D88.1 (K), U9.13 (OUT8)
unnamed: D89.1 (K), U9.17 (OUT12)
unnamed: D90.1 (K), U9.18 (OUT13)
unnamed: D91.1 (K), U5.11 (OUT6)
unnamed: D92.1 (K), U5.10 (OUT5)
unnamed: D93.1 (K), U5.9 (OUT4)
unnamed: D94.1 (K), U7.7 (OUT2)
unnamed: D95.1 (K), U7.6 (OUT1)
unnamed: D96.1 (K), U7.5 (OUT0)
unnamed: D97.1 (K), U7.20 (OUT15)
unnamed: D98.1 (K), U7.19 (OUT14)
unnamed: D99.1 (K), U7.18 (OUT13)
unnamed: D100.1 (K), U9.16 (OUT11)
unnamed: D101.1 (K), U9.15 (OUT10)
unnamed: D102.1 (K), U9.14 (OUT9)
unnamed: D103.1 (K), U6.7 (OUT2)
unnamed: D104.1 (K), U6.6 (OUT1)
unnamed: D105.1 (K), U6.19 (OUT14)
unnamed: D106.1 (K), U6.18 (OUT13)
unnamed: D107.1 (K), U7.9 (OUT4)
unnamed: D108.1 (K), U7.8 (OUT3)
unnamed: D109.1 (K), U7.12 (OUT7)
unnamed: D110.1 (K), U7.13 (OUT8)
unnamed: D111.1 (K), U7.17 (OUT12)
unnamed: D112.1 (K), U7.16 (OUT11)
unnamed: D113.1 (K), U8.7 (OUT2)
unnamed: D114.1 (K), U8.6 (OUT1)
unnamed: D115.1 (K), U8.8 (OUT3)
unnamed: D116.1 (K), U8.9 (OUT4)
unnamed: D117.1 (K), U6.8 (OUT3)
unnamed: D118.1 (K), U6.5 (OUT0)
unnamed: D119.1 (K), U6.20 (OUT15)
unnamed: D120.1 (K), U6.15 (OUT10)
unnamed: D121.1 (K), U7.10 (OUT5)
unnamed: D122.1 (K), U7.11 (OUT6)
unnamed: D123.1 (K), U7.14 (OUT9)
unnamed: D124.1 (K), U7.15 (OUT10)
unnamed: D125.1 (K), U8.10 (OUT5)
unnamed: D126.1 (K), U8.5 (OUT0)
unnamed: D127.1 (K), U8.20 (OUT15)
unnamed: D128.1 (K), U8.19 (OUT14)
unnamed: D129.1 (K), U6.10 (OUT5)
unnamed: D130.1 (K), U6.11 (OUT6)
unnamed: D131.1 (K), U6.12 (OUT7)
unnamed: D132.1 (K), U6.13 (OUT8)
unnamed: D133.1 (K), U6.14 (OUT9)
unnamed: D134.1 (K), U8.11 (OUT6)
unnamed: D135.1 (K), U8.12 (OUT7)
unnamed: D136.1 (K), U8.13 (OUT8)
unnamed: D137.1 (K), U8.14 (OUT9)
unnamed: D138.1 (K), U8.15 (OUT10)
unnamed: D139.1 (K), U6.9 (OUT4)
unnamed: D140.1 (K), U6.17 (OUT12)
unnamed: D141.1 (K), U6.16 (OUT11)
unnamed: D142.1 (K), U8.18 (OUT13)
unnamed: D143.1 (K), U8.17 (OUT12)
unnamed: D144.1 (K), U8.16 (OUT11)
unnamed: R4.1, U1.21 (GPIO17/U1TXD/ADC2_CH6)
unnamed: R5.1, U1.22 (GPIO18/U1RXD/ADC2_CH7/CLK_OUT3)
unnamed: R6.2, U1.23 (GPIO19/U1RTS/ADC2_CH8/CLK_OUT2/USB_D-)
unnamed: R7.2, U1.24 (GPIO20/U1CTS/ADC2_CH9/CLK_OUT1/USB_D+)
unnamed: R8.2, U2.23 (R-EXT)
unnamed: R9.2, U3.23 (R-EXT)
unnamed: R10.2, U4.23 (R-EXT)
unnamed: R11.2, U5.23 (R-EXT)
unnamed: R12.2, U6.23 (R-EXT)
unnamed: R13.2, U7.23 (R-EXT)
unnamed: R14.2, U8.23 (R-EXT)
unnamed: R15.2, U9.23 (R-EXT)
unnamed: R16.2, U10.23 (R-EXT)
unnamed: R20.1, R21.2, U11.1 (GND)
unnamed: U2.22 (SDO), U3.2 (SDI)
unnamed: U3.22 (SDO), U4.2 (SDI)
unnamed: U4.22 (SDO), U5.2 (SDI)
unnamed: U5.22 (SDO), U6.2 (SDI)
unnamed: U6.22 (SDO), U7.2 (SDI)
unnamed: U7.22 (SDO), U8.2 (SDI)
unnamed: U8.22 (SDO), U9.2 (SDI)
unnamed: U9.22 (SDO), U10.2 (SDI)

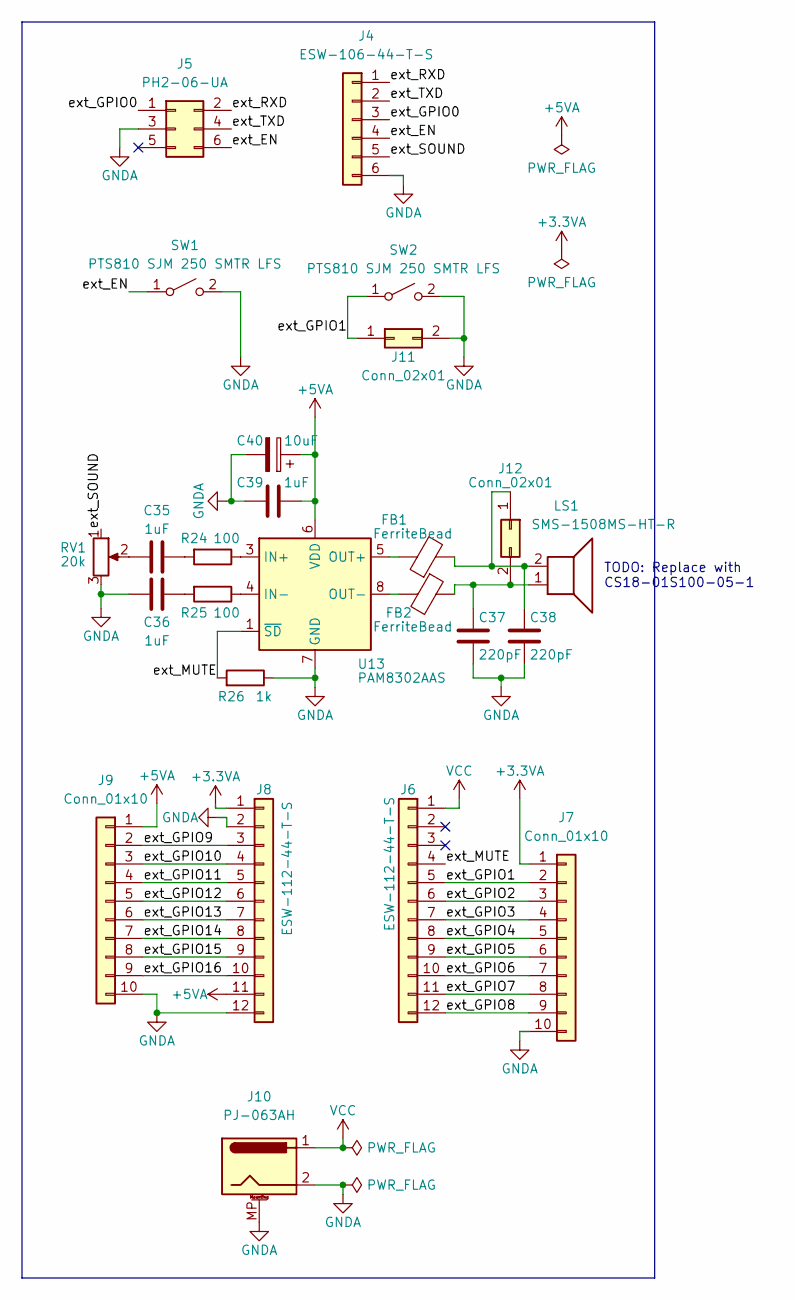
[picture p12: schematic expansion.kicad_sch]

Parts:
C35, C36, C39: 1uF; C_0805_2012Metric
C37, C38: 220pF; C_0805_2012Metric
C40: 10uF; CP_EIA-3216-10_Kemet-I
FB1, FB2: FerriteBead; C_0805_2012Metric
J4: ESW-106-44-T-S; PinSocket_1x06_P2.54mm_Vertical
J5: PH2-06-UA; PinHeader_2x03_P2.54mm_Vertical
J6, J8: ESW-112-44-T-S; PinSocket_1x12_P2.54mm_Vertical
J7, J9: Conn_01x10; PinHeader_1x10_P2.54mm_Vertical
J10: PJ-063AH; BarrelJack_CUI_PJ-063AH_Horizontal
J11, J12: Conn_02x01; PinHeader_1x02_P2.54mm_Vertical
LS1: SMS-1508MS-HT-R; SPKR_SMS-1508MS-HT-R
R24, R25: 100; R_0805_2012Metric
R26: 1k; R_0805_2012Metric
RV1: 20k; Potentiometer_Bourns_3339P_Vertical
SW1, SW2: PTS810 SJM 250 SMTR LFS; SW_SPST_PTS810
U13: PAM8302AAS; SOP-8_3.9x4.9mm_P1.27mm

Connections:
+3.3VA: J7.1, J8.1
+5VA: C39.1, C40.1, J8.11, J9.1, U13.6 (VDD)
/Expansion Module/ext_EN: J4.4, J5.6, SW1.1 (A)
/Expansion Module/ext_GPIO0: J4.3, J5.1
/Expansion Module/ext_GPIO1: J6.5, J7.2, J11.1, SW2.1 (A)
/Expansion Module/ext_GPIO2: J6.6, J7.3
/Expansion Module/ext_GPIO3: J6.7, J7.4
/Expansion Module/ext_GPIO4: J6.8, J7.5
/Expansion Module/ext_GPIO5: J6.9, J7.6
/Expansion Module/ext_GPIO6: J6.10, J7.7
/Expansion Module/ext_GPIO7: J6.11, J7.8
/Expansion Module/ext_GPIO8: J6.12, J7.9
/Expansion Module/ext_GPIO9: J8.3, J9.2
/Expansion Module/ext_GPIO10: J8.4, J9.3
/Expansion Module/ext_GPIO11: J8.5, J9.4
/Expansion Module/ext_GPIO12: J8.6, J9.5
/Expansion Module/ext_GPIO13: J8.7, J9.6
/Expansion Module/ext_GPIO14: J8.8, J9.7
/Expansion Module/ext_GPIO15: J8.9, J9.8
/Expansion Module/ext_GPIO16: J8.10, J9.9
/Expansion Module/ext_MUTE: J6.4, R26.2, U13.1 (~SD)
/Expansion Module/ext_RXD: J4.1, J5.2
/Expansion Module/ext_SOUND: J4.5, RV1.1
/Expansion Module/ext_TXD: J4.2, J5.4
GNDA: C36.2, C37.2, C38.2, C39.2, C40.2, J4.6, J5.3, J7.10, J8.2, J8.12, J9.10, J10.2, J10.MP (MountPin), J11.2, R26.1, RV1.3, SW1.2 (B), SW2.2 (B), U13.7 (GND)
unnamed: C35.1, R24.2
unnamed: C35.2, RV1.2
unnamed: C36.1, R25.2
unnamed: C37.1, FB2.1, J12.2, LS1.1
unnamed: C38.1, FB1.2, J12.1, LS1.2
unnamed: FB1.1, U13.5 (OUT+)
unnamed: FB2.2, U13.8 (OUT-)
unnamed: R24.1, U13.3 (IN+)
unnamed: R25.1, U13.4 (IN-)
VCC: J6.1, J10.1

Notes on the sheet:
TODO: Replace with CS18-01S100-05-1

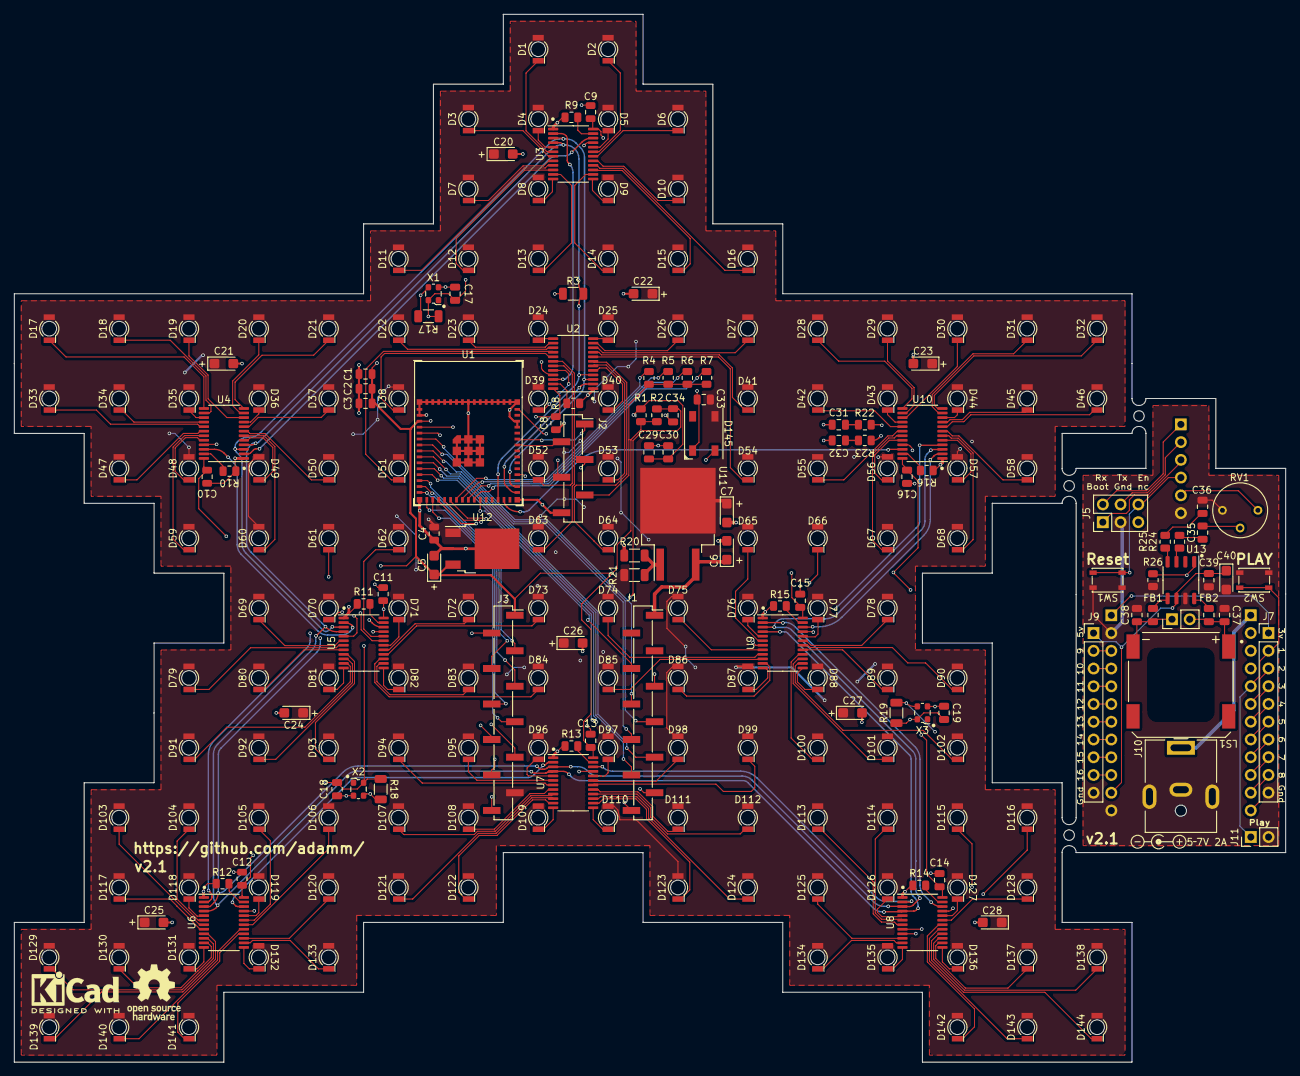
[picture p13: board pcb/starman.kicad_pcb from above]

Board: 4 copper layers, 182.0 x 150.0 mm, 247 parts (0 on the bottom side), 237 nets.

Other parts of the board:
LOGO1: KiCad-Logo2_5mm_SilkScreen
LOGO2: OSHW-Logo_7.5x8mm_SilkScreen

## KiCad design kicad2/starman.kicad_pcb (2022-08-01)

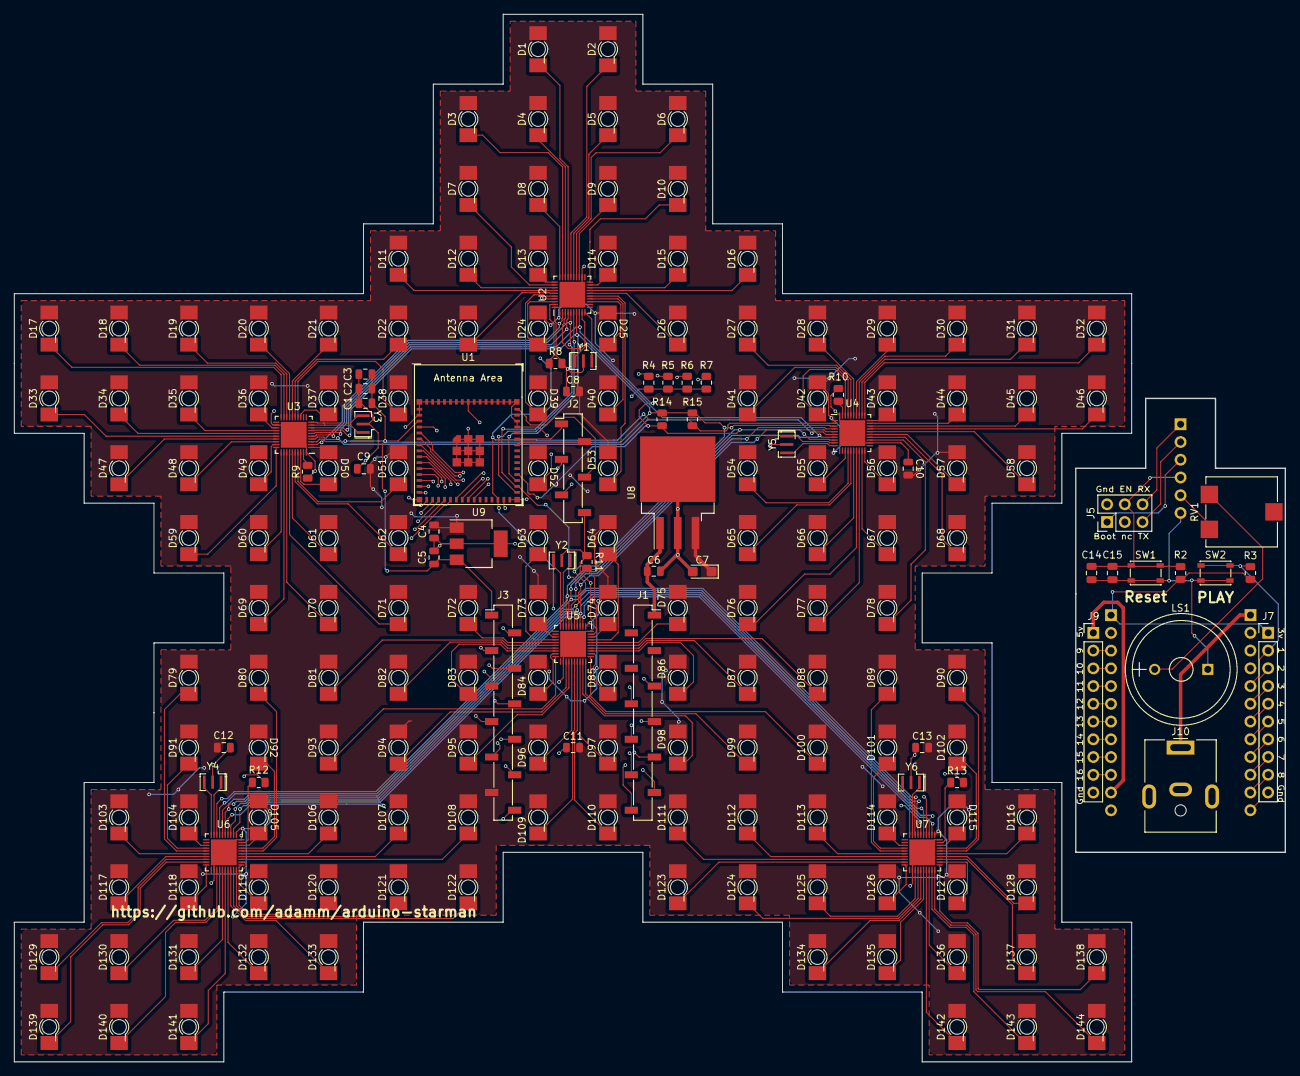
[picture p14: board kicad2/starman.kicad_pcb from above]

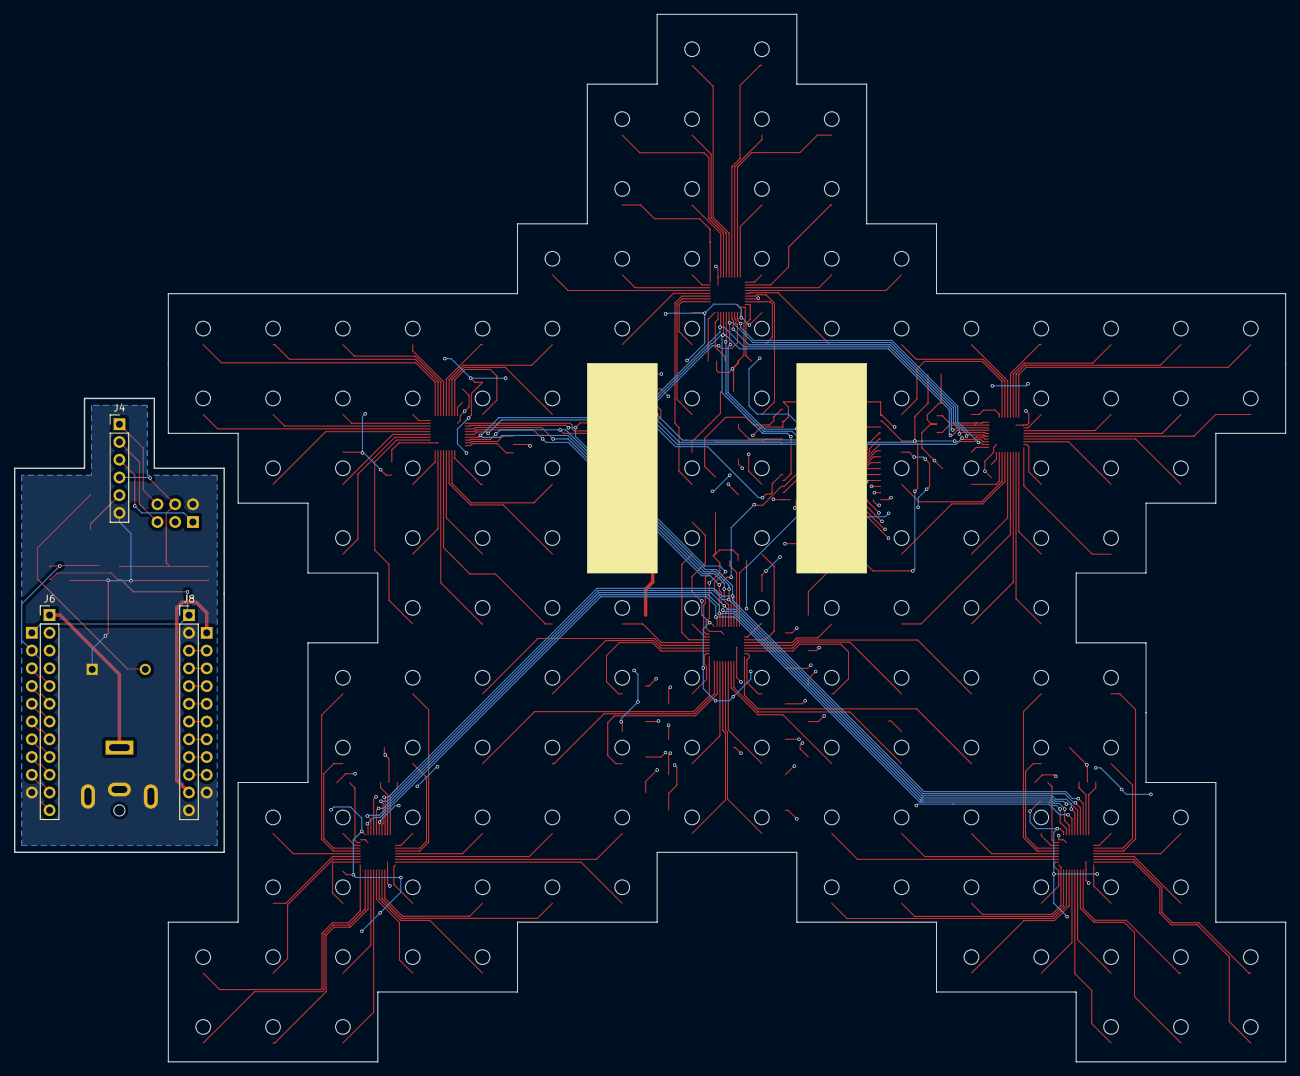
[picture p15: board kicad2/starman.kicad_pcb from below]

Board: 4 copper layers, 160.0 x 150.0 mm, 202 parts (3 on the bottom side), 228 nets.

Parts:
C1, C2: 10uF; C_0805_2012Metric
C3, C15: 1uF; C_0805_2012Metric
C4, C5, C8, C9, C10, C11, C12, C13: C; C_0805_2012Metric
C6, C14: 0.1uF; C_0805_2012Metric
C7: 10uF; CP_EIA-3216-10_Kemet-I
D1, D2, D3, D4, D5, D6, D7, D8, D9, D10, D11, D12, D13, D14, D15, D16, D17, D18, D19, D20, D21, D22, D23, D24, D25, D26, D27, D28, D29, D30, D31, D32, D33, D34, D35, D36, D37, D38, D39, D40, D41, D42, D43, D44, D45, D46, D47, D48, D49, D50, D51, D52, D53, D54, D55, D56, D57, D58, D59, D60, D61, D62, D63, D64, D65, D66, D67, D68, D69, D70, D71, D72, D73, D74, D75, D76, D77, D78, D79, D80, D81, D82, D83, D84, D85, D86, D87, D88, D89, D90, D91, D92, D93, D94, D95, D96, D97, D98, D99, D100, D101, D102, D103, D104, D105, D106, D107, D108, D109, D110, D111, D112, D113, D114, D115, D116, D117, D118, D119, D120, D121, D122, D123, D124, D125, D126, D127, D128, D129, D130, D131, D132, D133, D134, D135, D136, D137, D138, D139, D140, D141, D142, D143, D144: LED; LED_Osram_Lx_P47F_D2mm_ReverseMount
J1: Conn_01x12; PinSocket_1x12_P2.54mm_Vertical_SMD_Pin1Right
J2: Conn_01x10; PinSocket_1x06_P2.54mm_Vertical_SMD_Pin1Left
J3: Conn_01x12; PinSocket_1x12_P2.54mm_Vertical_SMD_Pin1Left
J4: Conn_01x06; PinHeader_1x06_P2.54mm_Vertical
J5: Conn_02x03_Counter_Clockwise; PinHeader_2x03_P2.54mm_Vertical
J6, J8: Conn_01x12; PinHeader_1x12_P2.54mm_Vertical
J7: Conn_01x10; PinHeader_1x10_P2.54mm_Vertical
J9: Conn_01x08; PinHeader_1x10_P2.54mm_Vertical
J10: Barrel_Jack_MountingPin; BarrelJack_CUI_PJ-063AH_Horizontal
LS1: Speaker; MagneticBuzzer_StarMicronics_HMB-06_HMB-12
R2, R3, R14, R15: 10k; R_0805_2012Metric
R4, R5, R6, R7: 75; R_0805_2012Metric
R8, R9, R10, R11, R12, R13: 3k; R_0805_2012Metric
RV1: 10k; Potentiometer_ACP_CA9-VSMD_Vertical
SW1, SW2: SW_SPST; SW_SPST_PTS810
U1: ESP32-S2-MINI-1
U2, U3, U4, U5, U6, U7: PCA9959; QFN-40_EP_5x5_Pitch0.4mm
U8: MIC29310-5.0WU; TO-263-3_TabPin2
U9: LF33_TO220; SOT-223-3_TabPin2
Y1, Y2, Y3, Y4, Y5, Y6: 20Mhz; Resonator_SMD_muRata_CSTxExxV-3Pin_3.0x1.1mm

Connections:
+3.3VA: J7.1, J8.1, R2.2, R3.2
+3V3: C1.2, C2.2, C3.2, C5.2, J3.1, R14.1, R15.1, U1.3 (3V3), U2.3 (VDDIO), U3.3 (VDDIO), U4.3 (VDDIO), U5.3 (VDDIO), U6.3 (VDDIO), U7.3 (VDDIO), U9.3 (VO)
+5V: C4.2, C7.1, C8.2, C9.2, C10.2, C11.2, C12.2, C13.2, D1.2 (A), D2.2 (A), D3.2 (A), D4.2 (A), D5.2 (A), D6.2 (A), D7.2 (A), D8.2 (A), D9.2 (A), D10.2 (A), D11.2 (A), D12.2 (A), D13.2 (A), D14.2 (A), D15.2 (A), D16.2 (A), D17.2 (A), D18.2 (A), D19.2 (A), D20.2 (A), D21.2 (A), D22.2 (A), D23.2 (A), D24.2 (A), D25.2 (A), D26.2 (A), D27.2 (A), D28.2 (A), D29.2 (A), D30.2 (A), D31.2 (A), D32.2 (A), D33.2 (A), D34.2 (A), D35.2 (A), D36.2 (A), D37.2 (A), D38.2 (A), D39.2 (A), D40.2 (A), D41.2 (A), D42.2 (A), D43.2 (A), D44.2 (A), D45.2 (A), D46.2 (A), D47.2 (A), D48.2 (A), D49.2 (A), D50.2 (A), D51.2 (A), D52.2 (A), D53.2 (A), D54.2 (A), D55.2 (A), D56.2 (A), D57.2 (A), D58.2 (A), D59.2 (A), D60.2 (A), D61.2 (A), D62.2 (A), D63.2 (A), D64.2 (A), D65.2 (A), D66.2 (A), D67.2 (A), D68.2 (A), D69.2 (A), D70.2 (A), D71.2 (A), D72.2 (A), D73.2 (A), D74.2 (A), D75.2 (A), D76.2 (A), D77.2 (A), D78.2 (A), D79.2 (A), D80.2 (A), D81.2 (A), D82.2 (A), D83.2 (A), D84.2 (A), D85.2 (A), D86.2 (A), D87.2 (A), D88.2 (A), D89.2 (A), D90.2 (A), D91.2 (A), D92.2 (A), D93.2 (A), D94.2 (A), D95.2 (A), D96.2 (A), D97.2 (A), D98.2 (A), D99.2 (A), D100.2 (A), D101.2 (A), D102.2 (A), D103.2 (A), D104.2 (A), D105.2 (A), D106.2 (A), D107.2 (A), D108.2 (A), D109.2 (A), D110.2 (A), D111.2 (A), D112.2 (A), D113.2 (A), D114.2 (A), D115.2 (A), D116.2 (A), D117.2 (A), D118.2 (A), D119.2 (A), D120.2 (A), D121.2 (A), D122.2 (A), D123.2 (A), D124.2 (A), D125.2 (A), D126.2 (A), D127.2 (A), D128.2 (A), D129.2 (A), D130.2 (A), D131.2 (A), D132.2 (A), D133.2 (A), D134.2 (A), D135.2 (A), D136.2 (A), D137.2 (A), D138.2 (A), D139.2 (A), D140.2 (A), D141.2 (A), D142.2 (A), D143.2 (A), D144.2 (A), J3.11, U2.1 (VDD), U3.1 (VDD), U4.1 (VDD), U5.1 (VDD), U6.1 (VDD), U7.1 (VDD), U8.3 (VO), U9.1 (VI)
+5VA: J8.11, J9.1
/CS: U1.33 (GPIO37), U2.7 (/CS), U3.7 (/CS), U4.7 (/CS), U5.7 (/CS), U6.7 (/CS), U7.7 (/CS)
/EN: J2.4, U1.45 (CHIP/PU/RESET)
/GPIO0: J2.3, U1.4 (GPIO0/BOOT)
/GPIO1: J1.5, U1.5 (GPIO1/ADC1_CH0)
/GPIO2: J1.6, U1.6 (GPIO2/ADC1_CH1)
/GPIO3: J1.7, U1.7 (GPIO3/ADC1_CH2)
/GPIO4: J1.8, U1.8 (GPIO4/ADC1_CH3)
/GPIO5: J1.9, U1.9 (GPIO5/ADC1_CH4)
/GPIO6: J1.10, U1.10 (GPIO6/ADC1_CH5)
/GPIO7: J1.11, U1.11 (GPIO7/ADC1_CH6)
/GPIO8: J1.12, U1.12 (GPIO8/ADC1_CH7)
/GPIO9: J3.3, U1.13 (GPIO9/ADC1_CH8)
/GPIO10: J3.4, U1.14 (GPIO10/ADC1_CH9)
/GPIO11: J3.5, U1.15 (GPIO11/ADC2_CH0)
/GPIO12: J3.6, U1.16 (GPIO12/ADC2_CH1)
/GPIO13: J3.7, U1.17 (GPIO13/ADC2_CH2)
/GPIO14: J3.8, U1.18 (GPIO14/ADC2_CH3)
/GPIO15: J3.9, U1.19 (GPIO15/ADC2_CH4/XTAL_32K_P)
/GPIO16: J3.10, U1.20 (GPIO16/ADC2_CH5/XTAL_32K_N)
/MISO: U1.29 (GPIO34), U7.4 (SDO)
/MOSI: U1.31 (GPIO35), U2.6 (SDI)
/OE: R14.2, U1.34 (GPIO38), U2.8 (/OE), U3.8 (/OE), U4.8 (/OE), U5.8 (/OE), U6.8 (/OE), U7.8 (/OE)
/RESET: R15.2, U1.28 (GPIO33), U2.2 (/RESET), U3.2 (/RESET), U4.2 (/RESET), U5.2 (/RESET), U6.2 (/RESET), U7.2 (/RESET)
/RXD: J2.1, U1.40 (GPIO44/U0RXD/PROG)
/SCLK: U1.32 (GPIO36), U2.5 (SCLK), U3.5 (SCLK), U4.5 (SCLK), U5.5 (SCLK), U6.5 (SCLK), U7.5 (SCLK)
/SOUND: J2.5, R4.1, R5.1, R6.1, R7.1
/TXD: J2.2, U1.39 (GPIO43/U0TXD/PROG)
/ext_EN: C14.2, C15.2, J4.4, J5.4, R2.1, SW1.1 (A)
/ext_GPIO0: J4.3, J5.1
/ext_GPIO1: J6.5, J7.2, R3.1, SW2.1 (A)
/ext_GPIO2: J6.6, J7.3
/ext_GPIO3: J6.7, J7.4
/ext_GPIO4: J6.8, J7.5
/ext_GPIO5: J6.9, J7.6
/ext_GPIO6: J6.10, J7.7
/ext_GPIO7: J6.11, J7.8
/ext_GPIO8: J6.12, J7.9
/ext_GPIO9: J8.3, J9.2
/ext_GPIO10: J8.4, J9.3
/ext_GPIO11: J8.5, J9.4
/ext_GPIO12: J8.6, J9.5
/ext_GPIO13: J8.7, J9.6
/ext_GPIO14: J8.8, J9.7
/ext_GPIO15: J8.9, J9.8
/ext_GPIO16: J8.10, J9.9
/ext_RXD: J4.1, J5.6
/ext_SOUND: J4.5, RV1.1
/ext_TXD: J4.2, J5.5
GND: C1.1, C2.1, C3.1, C4.1, C5.1, C6.1, C7.2, C8.1, C9.1, C10.1, C11.1, C12.1, C13.1, J2.6, J3.2, J3.12, R8.1, R9.1, R10.1, R11.1, R12.1, R13.1, U1.1 (GND), U1.2 (GND), U1.30 (GND), U1.42 (GND), U1.43 (GND), U1.46 (GND), U2.22 (VSS), U2.40 (VSS), U2.41 (PAD), U3.22 (VSS), U3.40 (VSS), U3.41 (PAD), U4.22 (VSS), U4.40 (VSS), U4.41 (PAD), U5.22 (VSS), U5.40 (VSS), U5.41 (PAD), U6.22 (VSS), U6.40 (VSS), U6.41 (PAD), U7.22 (VSS), U7.40 (VSS), U7.41 (PAD), U8.2 (GND), U9.2 (GND), Y1.2, Y2.2, Y3.2, Y4.2, Y5.2, Y6.2
GNDA: C14.1, C15.1, J4.6, J5.2, J7.10, J8.2, J8.12, J9.10, J10.2, J10.MP (MountPin), LS1.1, SW1.2 (B), SW2.2 (B)
unnamed: C6.2, J1.1, U8.1 (VI)
unnamed: D1.1 (K), U2.27 (LED12)
unnamed: D2.1 (K), U2.26 (LED11)
unnamed: D3.1 (K), U2.29 (LED14)
unnamed: D4.1 (K), U2.28 (LED13)
unnamed: D5.1 (K), U2.25 (LED10)
unnamed: D6.1 (K), U2.24 (LED9)
unnamed: D7.1 (K), U2.32 (LED17)
unnamed: D8.1 (K), U2.30 (LED15)
unnamed: D9.1 (K), U2.23 (LED8)
unnamed: D10.1 (K), U2.20 (LED7)
unnamed: D11.1 (K), U2.34 (LED19)
unnamed: D12.1 (K), U2.33 (LED18)
unnamed: D13.1 (K), U2.31 (LED16)
unnamed: D14.1 (K), U2.19 (LED6)
unnamed: D15.1 (K), U2.18 (LED5)
unnamed: D16.1 (K), U2.17 (LED4)
unnamed: D17.1 (K), U3.20 (LED7)
unnamed: D18.1 (K), U3.19 (LED6)
unnamed: D19.1 (K), U3.18 (LED5)
unnamed: D20.1 (K), U3.17 (LED4)
unnamed: D21.1 (K), U3.16 (LED3)
unnamed: D22.1 (K), U3.15 (LED2)
unnamed: D23.1 (K), U2.35 (LED20)
unnamed: D24.1 (K), U2.38 (LED23)
unnamed: D25.1 (K), U2.13 (LED0)
unnamed: D26.1 (K), U2.16 (LED3)
unnamed: D27.1 (K), U4.36 (LED21)
unnamed: D28.1 (K), U4.35 (LED20)
unnamed: D29.1 (K), U4.34 (LED19)
unnamed: D30.1 (K), U4.33 (LED18)
unnamed: D31.1 (K), U4.32 (LED17)
unnamed: D32.1 (K), U4.31 (LED16)
unnamed: D33.1 (K), U3.26 (LED11)
unnamed: D34.1 (K), U3.25 (LED10)
unnamed: D35.1 (K), U3.24 (LED9)
unnamed: D36.1 (K), U3.23 (LED8)
unnamed: D37.1 (K), U3.13 (LED0)
unnamed: D38.1 (K), U3.14 (LED1)
unnamed: D39.1 (K), U2.36 (LED21)
unnamed: D40.1 (K), U2.14 (LED1)
unnamed: D41.1 (K), U4.37 (LED22)
unnamed: D42.1 (K), U4.38 (LED23)
unnamed: D43.1 (K), U4.30 (LED15)
unnamed: D44.1 (K), U4.29 (LED14)
unnamed: D45.1 (K), U4.28 (LED13)
unnamed: D46.1 (K), U4.27 (LED12)
unnamed: D47.1 (K), U3.27 (LED12)
unnamed: D48.1 (K), U3.28 (LED13)
unnamed: D49.1 (K), U3.29 (LED14)
unnamed: D50.1 (K), U3.38 (LED23)
unnamed: D51.1 (K), U3.37 (LED22)
unnamed: D52.1 (K), U2.37 (LED22)
unnamed: D53.1 (K), U2.15 (LED2)
unnamed: D54.1 (K), U4.14 (LED1)
unnamed: D55.1 (K), U4.13 (LED0)
unnamed: D56.1 (K), U4.20 (LED7)
unnamed: D57.1 (K), U4.25 (LED10)
unnamed: D58.1 (K), U4.26 (LED11)
unnamed: D59.1 (K), U3.30 (LED15)
unnamed: D60.1 (K), U3.31 (LED16)
unnamed: D61.1 (K), U3.35 (LED20)
unnamed: D62.1 (K), U3.36 (LED21)
unnamed: D63.1 (K), U5.14 (LED1)
unnamed: D64.1 (K), U5.37 (LED22)
unnamed: D65.1 (K), U4.15 (LED2)
unnamed: D66.1 (K), U4.16 (LED3)
unnamed: D67.1 (K), U4.19 (LED6)
unnamed: D68.1 (K), U4.24 (LED9)
unnamed: D69.1 (K), U3.32 (LED17)
unnamed: D70.1 (K), U3.33 (LED18)
unnamed: D71.1 (K), U3.34 (LED19)
unnamed: D72.1 (K), U5.15 (LED2)
unnamed: D73.1 (K), U5.13 (LED0)
unnamed: D74.1 (K), U5.38 (LED23)
unnamed: D75.1 (K), U5.36 (LED21)
unnamed: D76.1 (K), U4.17 (LED4)
unnamed: D77.1 (K), U4.18 (LED5)
unnamed: D78.1 (K), U4.23 (LED8)
unnamed: D79.1 (K), U6.15 (LED2)
unnamed: D80.1 (K), U6.36 (LED21)
unnamed: D81.1 (K), U5.16 (LED3)
unnamed: D82.1 (K), U5.17 (LED4)
unnamed: D83.1 (K), U5.18 (LED5)
unnamed: D84.1 (K), U5.19 (LED6)
unnamed: D85.1 (K), U5.32 (LED17)
unnamed: D86.1 (K), U5.33 (LED18)
unnamed: D87.1 (K), U5.34 (LED19)
unnamed: D88.1 (K), U5.35 (LED20)
unnamed: D89.1 (K), U7.15 (LED2)
unnamed: D90.1 (K), U7.36 (LED21)
unnamed: D91.1 (K), U6.14 (LED1)
unnamed: D92.1 (K), U6.37 (LED22)
unnamed: D93.1 (K), U5.20 (LED7)
unnamed: D94.1 (K), U5.23 (LED8)
unnamed: D95.1 (K), U5.24 (LED9)
unnamed: D96.1 (K), U5.25 (LED10)
unnamed: D97.1 (K), U5.28 (LED13)
unnamed: D98.1 (K), U5.29 (LED14)
unnamed: D99.1 (K), U5.30 (LED15)
unnamed: D100.1 (K), U5.31 (LED16)
unnamed: D101.1 (K), U7.14 (LED1)
unnamed: D102.1 (K), U7.37 (LED22)
unnamed: D103.1 (K), U6.16 (LED3)
unnamed: D104.1 (K), U6.13 (LED0)
unnamed: D105.1 (K), U6.38 (LED23)
unnamed: D106.1 (K), U6.35 (LED20)
unnamed: D107.1 (K), U6.34 (LED19)
unnamed: D108.1 (K), U6.33 (LED18)
unnamed: D109.1 (K), U5.26 (LED11)
unnamed: D110.1 (K), U5.27 (LED12)
unnamed: D111.1 (K), U7.18 (LED5)
unnamed: D112.1 (K), U7.17 (LED4)
unnamed: D113.1 (K), U7.16 (LED3)
unnamed: D114.1 (K), U7.13 (LED0)
unnamed: D115.1 (K), U7.38 (LED23)
unnamed: D116.1 (K), U7.35 (LED20)
unnamed: D117.1 (K), U6.17 (LED4)
unnamed: D118.1 (K), U6.20 (LED7)
unnamed: D119.1 (K), U6.32 (LED17)
unnamed: D120.1 (K), U6.31 (LED16)
unnamed: D121.1 (K), U6.30 (LED15)
unnamed: D122.1 (K), U6.29 (LED14)
unnamed: D123.1 (K), U7.19 (LED6)
unnamed: D124.1 (K), U7.24 (LED9)
unnamed: D125.1 (K), U7.23 (LED8)
unnamed: D126.1 (K), U7.20 (LED7)
unnamed: D127.1 (K), U7.32 (LED17)
unnamed: D128.1 (K), U7.34 (LED19)
unnamed: D129.1 (K), U6.18 (LED5)
unnamed: D130.1 (K), U6.23 (LED8)
unnamed: D131.1 (K), U6.25 (LED10)
unnamed: D132.1 (K), U6.27 (LED12)
unnamed: D133.1 (K), U6.28 (LED13)
unnamed: D134.1 (K), U7.25 (LED10)
unnamed: D135.1 (K), U7.26 (LED11)
unnamed: D136.1 (K), U7.28 (LED13)
unnamed: D137.1 (K), U7.33 (LED18)
unnamed: D138.1 (K), U7.31 (LED16)
unnamed: D139.1 (K), U6.19 (LED6)
unnamed: D140.1 (K), U6.24 (LED9)
unnamed: D141.1 (K), U6.26 (LED11)
unnamed: D142.1 (K), U7.27 (LED12)
unnamed: D143.1 (K), U7.29 (LED14)
unnamed: D144.1 (K), U7.30 (LED15)
unnamed: R4.2, U1.21 (ADC2_CH7/DAC_2/GPIO17)
unnamed: R5.2, U1.22 (ADC2_CH6/DAC_1/GPIO18)
unnamed: R6.2, U1.23 (USB_D-/ADC2_CH8/GPIO19)
unnamed: R7.2, U1.24 (USB_D+/ADC2_CH9/GPIO20)
unnamed: R8.2, U2.39 (REXT)
unnamed: R9.2, U3.39 (REXT)
unnamed: R10.2, U4.39 (REXT)
unnamed: R11.2, U5.39 (REXT)
unnamed: R12.2, U6.39 (REXT)
unnamed: R13.2, U7.39 (REXT)
unnamed: LS1.2, RV1.3
unnamed: U2.4 (SDO), U3.6 (SDI)
unnamed: U2.9 (OSCIN), Y1.1
unnamed: U2.10 (OSCOUT), Y1.3
unnamed: U3.4 (SDO), U4.6 (SDI)
unnamed: U3.9 (OSCIN), Y3.1
unnamed: U3.10 (OSCOUT), Y3.3
unnamed: U4.4 (SDO), U5.6 (SDI)
unnamed: U4.9 (OSCIN), Y5.1
unnamed: U4.10 (OSCOUT), Y5.3
unnamed: U5.4 (SDO), U6.6 (SDI)
unnamed: U5.9 (OSCIN), Y2.1
unnamed: U5.10 (OSCOUT), Y2.3
unnamed: U6.4 (SDO), U7.6 (SDI)
unnamed: U6.9 (OSCIN), Y4.1
unnamed: U6.10 (OSCOUT), Y4.3
unnamed: U7.9 (OSCIN), Y6.1
unnamed: U7.10 (OSCOUT), Y6.3
VCC: J6.1, J10.1

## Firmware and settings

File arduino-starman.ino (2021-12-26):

/***************************************************

    Arduino Starman Christmas Ornament
    Copyright (C) 2018-2021  Adam McDaniel

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
  ------

  * 24 randomly fading LEDs
  * 24 synchronized LEDs with music playback

  * Press the button to start the game.
  * Start the game with three lives at level 1 (overworld).  If you lose all lives, it's game over.
  * There is a 50% chance you will complete each level.  If you do, you move onto next level.  If not, you die and need to retry.
    * Death can occur randomly within the level.
    * Press the button again to start the next level, or retry the same level.
  * There is a 40% chance you'll get a star.
    * Stars can occur randomly within the level.
    * Stars do not negate death (ie, falling into a pit).
  * There is a 25% chance you'll get a 1-up, resulting in an extra life.
  * If you make it to level 4 (castle) and complete it, there is a 25% chance the princess will be there and the game is over.
    * If the princess is in another castle, restart at level 1 with current number of lives.

 ****************************************************/

#include <WiFi.h>
#include <WiFiClient.h>
#include <WebServer.h>
#include <ESPmDNS.h>
#include <ArduinoOTA.h>

#include "Adafruit_TLC5947.h"
#include "Playtune.h"
#include "smb.h"
#include "secret.h"

const char *ssid = WIFI_SSID;
const char *password = WIFI_PASSWD;


WebServer server(80);

#define STATUS_LED  19
#define BUTTON_PIN  4
#define AUDIO_1_PIN 18
#define AUDIO_2_PIN 5
#define AUDIO_3_PIN 17
#define AUDIO_4_PIN 16
#define DATA_PIN    26
#define CLOCK_PIN   25
#define DISABLE_PIN 33
#define LATCH_PIN   32

#define elements(x) (sizeof(x) / sizeof((x)[0]))

Adafruit_TLC5947 tlc = Adafruit_TLC5947(1, CLOCK_PIN, DATA_PIN, LATCH_PIN);

#define TOTAL_LEDS 24
#define FADE_LEDS 18

uint8_t active[FADE_LEDS];  // active leds
int16_t bright[FADE_LEDS];  // current brightness value
int8_t delta[FADE_LEDS];    // current brightness delta
volatile uint8_t stage = -1;         // music stage (0 = no music active)

uint8_t alternate[]  = {0, 1, 0, 1, 0, 1, 0, 1, 0, 1, 0, 1, 0, 1, 0, 1, 0, 1, 0, 1, 0, 1, 0, 1};
uint8_t shortdot[]   = {0, 0, 0, 1, 0, 0, 0, 1, 0, 0, 0, 1, 0, 0, 0, 1, 0, 0, 0, 1, 0, 0, 0, 1};
uint8_t longdot[]    = {0, 0, 0, 0, 0, 0, 0, 1, 0, 0, 0, 0, 0, 0, 0, 1, 0, 0, 0, 0, 0, 0, 0, 1};
uint8_t shortdash[]  = {0, 0, 1, 1, 0, 0, 1, 1, 0, 0, 1, 1, 0, 0, 1, 1, 0, 0, 1, 1, 0, 0, 1, 1};
uint8_t widedash[]   = {0, 1, 1, 1, 0, 1, 1, 1, 0, 1, 1, 1, 0, 1, 1, 1, 0, 1, 1, 1, 0, 1, 1, 1};
uint8_t longdash[]   = {0, 0, 0, 0, 1, 1, 1, 1, 0, 0, 0, 0, 1, 1, 1, 1, 0, 0, 0, 0, 1, 1, 1, 1};
uint8_t allpoints[]  = {1, 1, 1, 1, 1, 1, 1, 1, 1, 1, 1, 1, 1, 1, 1, 1, 1, 1, 1, 1, 1, 1, 1, 1};
uint8_t halfpoints[] = {0, 0, 0, 0, 0, 0, 0, 0, 0, 0, 0, 0, 1, 1, 1, 1, 1, 1, 1, 1, 1, 1, 1, 1};

void marquee(uint8_t *pattern);
void flash(uint8_t *pattern);

struct demo {
  const unsigned char *music;
  void (*sequence)(uint8_t*);
  uint8_t *pattern;
};

#define STARTING_LIVES    3
#define STARTING_LEVEL    0
#define MAX_STAR_PERCENT 40
#define MAX_1UP_PERCENT  25
#define MAX_FINISHED_LEVEL_PERCENT 50
#define MAX_FINISHED_GAME_PERCENT  25

int8_t lives = STARTING_LIVES;
int8_t level = STARTING_LEVEL;
uint32_t marioDiesAtPos = -1;

demo levels[] = {
  { .music = smb_overworld, .sequence = &marquee, .pattern = widedash },
  { .music = smb_underworld, .sequence = &marquee, .pattern = longdot },
  { .music = smb_underwater, .sequence = &marquee, .pattern = halfpoints },
  { .music = smb_castle, .sequence = &marquee, .pattern = longdot },
};

demo invincibility[] = {
  { .music = smb_block, .sequence = &marquee, .pattern = longdot },
  { .music = smb_powerup, .sequence = &flash, .pattern = allpoints },
  { .music = smb_starman, .sequence = &marquee, .pattern = widedash },
};

demo oneUp[] = {
  { .music = smb_block, .sequence = &marquee, .pattern = longdot },
  { .music = smb_1up, .sequence = &flash, .pattern = allpoints },
};

demo levelfinish[] = {
  { .music = smb_course_clear, .sequence = &marquee, .pattern = longdash },
  { .music = smb_fanfare, .sequence = &marquee, .pattern = shortdash },
  { .music = smb_ending, .sequence = &marquee, .pattern = widedash },
}; // randomly pick 1 if not castle, or 2 plus maybe 3 if castle, or death

demo levelfailed[] = {
  { .music = smb_death, .sequence = &marquee, .pattern = longdash },
  { .music = smb_gameover, .sequence = &marquee, .pattern = widedash },
}; // randomly pick 1, 2, or 3 instead of levelfinish

demo stardemo[] = {
  { .music = NULL, .sequence = NULL, .pattern = NULL },
  { .music = NULL, .sequence = NULL, .pattern = NULL },
  { .music = NULL, .sequence = NULL, .pattern = NULL },
  { .music = NULL, .sequence = NULL, .pattern = NULL },
  { .music = NULL, .sequence = NULL, .pattern = NULL },
  { .music = NULL, .sequence = NULL, .pattern = NULL },
  { .music = NULL, .sequence = NULL, .pattern = NULL },
  { .music = NULL, .sequence = NULL, .pattern = NULL },
};


void handleRoot() {
  char temp[1024];
  int sec = millis() / 1000;
  int min = sec / 60;
  int hr = min / 60;

  snprintf(temp, 1024,

           "<html>\
  <head>\
    <title>Starman Christmas Ornament</title>\
    <style>\
      body { background-color: #cccccc; font-family: Arial, Helvetica, Sans-Serif; Color: #000088; }\
    </style>\
    <script>\
      function play_music() {\
        const Http = new XMLHttpRequest();\
        const url = '/play';\
        Http.open('GET', url);\
        Http.send();\
      }\
    </script>\
  </head>\
  <body>\
    <h1>Starman! &#127776;</h1>\
    <button onclick='play_music()'>Play Music</button>\
    <p>Lives: %d</p>\
    <p>Current Level: %d</p>\
    <p>Tune playing: %d</p>\
    <p>Tune stage: %d</p>\
    <p>Uptime: %02d:%02d:%02d</p>\
  </body>\
</html>",
           lives, level + 1, tune_playing, stage, hr, min % 60, sec % 60
          );
  server.send(200, "text/html", temp);
}

void handlePlayButton() {
  if (stage == 0) {
    playLevel();
    stage = 1;
  }

  server.send(200, "text/html", "OK");
}


void handleNotFound() {
  String message = "File Not Found\n\n";
  message += "URI: ";
  message += server.uri();
  message += "\nMethod: ";
  message += (server.method() == HTTP_GET) ? "GET" : "POST";
  message += "\nArguments: ";
  message += server.args();
  message += "\n";

  for (uint8_t i = 0; i < server.args(); i++) {
    message += " " + server.argName(i) + ": " + server.arg(i) + "\n";
  }

  server.send(404, "text/plain", message);
}


void setup() {
  Serial.begin(115200);
  Serial.println("startup");

  pinMode(STATUS_LED, OUTPUT);
  pinMode(BUTTON_PIN, INPUT_PULLUP);
  pinMode(DISABLE_PIN, OUTPUT);
  digitalWrite(STATUS_LED, false);
  digitalWrite(DISABLE_PIN, true);

  WiFi.mode(WIFI_STA);
  WiFi.begin(ssid, password);
  
  // Wait for connection
  while (WiFi.status() != WL_CONNECTED) {
    digitalWrite(STATUS_LED, !digitalRead(STATUS_LED));
    delay(500);
    Serial.print(".");
  }
  digitalWrite(STATUS_LED, false);
  Serial.println("");
  Serial.print("Connected to ");
  Serial.println(ssid);
  Serial.print("IP address: ");
  Serial.println(WiFi.localIP());

  ArduinoOTA.onStart([]() {
    Serial.println("Start updating..");
  }).onEnd([]() {
    digitalWrite(STATUS_LED, false);
    Serial.println("\n\nDone!");
  }).onProgress([](unsigned int progress, unsigned int total) {
    Serial.printf("Progress: %u%%\r", (progress / (total / 100)));
    digitalWrite(STATUS_LED, !digitalRead(STATUS_LED));
  }).onError([](ota_error_t error) {
    Serial.printf("Error[%u]: ", error);
    if (error == OTA_AUTH_ERROR) Serial.println("Auth Failed");
    else if (error == OTA_BEGIN_ERROR) Serial.println("Begin Failed");
    else if (error == OTA_CONNECT_ERROR) Serial.println("Connect Failed");
    else if (error == OTA_RECEIVE_ERROR) Serial.println("Receive Failed");
    else if (error == OTA_END_ERROR) Serial.println("End Failed");
  });
  ArduinoOTA.begin();

  if (MDNS.begin("starman")) {
    Serial.println("MDNS responder started");
  }

  server.on("/", handleRoot);
  server.on("/play", handlePlayButton);
  server.onNotFound(handleNotFound);
  server.begin();

  tune_initchan(AUDIO_1_PIN);
  tune_initchan(AUDIO_2_PIN);
  tune_initchan(AUDIO_3_PIN);
  tune_initchan(AUDIO_4_PIN);
  tune_callback(&callback);
  Serial.println("Music ready");

  for (uint8_t i = 0; i < FADE_LEDS; i++) {
    active[i] = i;
    bright[i] = (rand() % 4096);
    delta[i] = (rand() & 400) - 200;
  }
  shuffle(active, FADE_LEDS);

  tlc.begin();
  digitalWrite(DISABLE_PIN, false);
  Serial.println("LEDs ready");
  stage = 0;
}


void playLevel() {
  uint8_t pos = 1;
  boolean gotStar = 0, got1up = 0, finishedLevel = 0, finishedGame = 0;

  randomSeed(millis());

  long chanceStar = random(100);
  long chance1up  = random(100);
  long chanceFinishedLevel = random(100);
  long chanceFinishedGame  = random(100);

  Serial.printf("Lives Remaining: %d\n", lives);
  Serial.printf("Play level: %d\n", level);

  Serial.printf("Random star (%d or lower)? %d\n", MAX_STAR_PERCENT, chanceStar);
  if (chanceStar <= MAX_STAR_PERCENT)
    gotStar = 1;
  
  Serial.printf("Random 1up (%d or lower)? %d\n", MAX_1UP_PERCENT, chance1up);
  if (chance1up <= MAX_1UP_PERCENT)
    got1up = 1;

  Serial.printf("Random finished level (%d or lower)? %d\n", MAX_FINISHED_LEVEL_PERCENT, chanceFinishedLevel);
  if (chanceFinishedLevel <= MAX_FINISHED_LEVEL_PERCENT)
    finishedLevel = 1;

  if (!finishedLevel) {
    uint32_t musicBytes = 0;
    byte data = 0;
    while (data != 0xf0) {
      data = pgm_read_byte(levels[level].music + musicBytes++);
    }
    marioDiesAtPos = random(musicBytes);
    Serial.printf("Mario will die at music position %d of %d\n", marioDiesAtPos, musicBytes);
  }
  else {
    marioDiesAtPos = -1;
  }

  if (level == 3) {
    Serial.printf("Random finished game (%d or lower)? %d\n", MAX_FINISHED_GAME_PERCENT, chanceFinishedGame);
    if (chanceFinishedGame <= MAX_FINISHED_GAME_PERCENT)
      finishedGame = 1;
  }

  memset(stardemo, 0, sizeof(stardemo));
  
  stardemo[pos++] = levels[level];

  if (gotStar) {
    Serial.println("Play starman invincibility");
    for (uint8_t i = 0; i < elements(invincibility); i++) {
      stardemo[pos++] = invincibility[i];
    }
  }

  if (got1up) { 
    Serial.println("Play 1-Up");
    for (uint8_t i = 0; i < elements(oneUp); i++) {
      stardemo[pos++] = oneUp[i];
    }
    lives++;
  }

  if (finishedLevel) {
    // lived
    Serial.println("Mario Lived!");
    if (level < 3) {
      stardemo[pos++] = levelfinish[0];
      Serial.println("Play Flagpole");
      level++;
    }
    else {
      Serial.println("Play Fanfare");
      stardemo[pos++] = levelfinish[1];
      if (finishedGame) {
        Serial.println("Play Ending");
        stardemo[pos++] = levelfinish[2];
        lives = STARTING_LIVES;
      }
      level = STARTING_LEVEL;
    }
  }
  else {
    // died
    Serial.println("Mario Died!");
    stardemo[pos++] = levelfailed[0];
    if (--lives == 0) {
      Serial.println("Play GameOver");
      stardemo[pos++] = levelfailed[1];
      lives = STARTING_LIVES;
      level = STARTING_LEVEL;
    }
  }
}



void callback(uint32_t pos) {
  // Callback function called once per note.  Increment LED pattern on each note.
  void (*sequence)(uint8_t*) = stardemo[stage].sequence;
  uint8_t *pattern  = stardemo[stage].pattern;

  Serial.printf("Playing music at byte: %d\n", pos);

  if (pos > marioDiesAtPos) {
    tune_stopscore();
    marioDiesAtPos = -1;
  }

  sequence(pattern);
  tlc.write();
}


void loop() {
  server.handleClient();
  ArduinoOTA.handle();
  delay(2);//allow the cpu to switch to other tasks
  
  if (stage == 0) {
    fade();
    tlc.write();
    bool buttonState = digitalRead(BUTTON_PIN);
    if (buttonState == 0) {
      playLevel();
      stage = 1;
    }
  }
  else if (stage >= 1) {
    Serial.print("playing stage");
    Serial.println(stage);
    tune_playscore(stardemo[stage].music);
    while (tune_playing) {
      // As we block the main thread here, we still want the web server to handle requests.
      server.handleClient(); 
      ArduinoOTA.handle();
      delay(2);
    }
    tune_delay(100); /* wait a moment */
    stage++;
    if (stage == elements(stardemo) ||
        stardemo[stage].music == NULL ) {
      stage = 0;
    }
  }
}


void fade() {
  for (uint8_t i = 0; i < FADE_LEDS; i++) {
    int16_t brightness;

    bright[i] += delta[i];
    brightness = bright[i];

    if (bright[i] >= 4095) {
      brightness = 4095;
      delta[i] *= -1;
    }
    if (bright[i] <= 0) {
      brightness = 0;
      delta[i] *= -1;
    }

    tlc.setPWM(active[i], brightness);

    if (bright[i] <= 0) {
      // randomly select a different LED not already in active array;
      if (FADE_LEDS < TOTAL_LEDS) {
        boolean new_number = true;
        while (new_number) {
          uint8_t new_active = (rand() % 24);
          new_number = false;
          for (uint8_t j = 0; j < FADE_LEDS; j++) {
            if (active[j] == new_active) {
              new_number = true;
            }
          }
          if (!new_number)
            active[i] = new_active;
        }
      }
    }
  }
  delay(20);
}

void marquee(uint8_t *pattern) {
  for (uint8_t i = 0; i < TOTAL_LEDS; i++) {
    if (pattern[i])
      tlc.setPWM(i, 4095);
    else
      tlc.setPWM(i, 512);
  }

  uint8_t tmp = pattern[0];
  for (uint8_t i = 0; i < TOTAL_LEDS-1; i++) {
    pattern[i] = pattern[i + 1];
  }
  pattern[TOTAL_LEDS-1] = tmp;
}


void flash(uint8_t *pattern) {
  for (uint8_t i = 0; i < TOTAL_LEDS; i++) {
    if (pattern[i])
      tlc.setPWM(i, 4095);
    else
      tlc.setPWM(i, 256);
  }

  for (uint8_t i = 0; i < TOTAL_LEDS; i++) {
    pattern[i] = !pattern[i];
  }
}


void shuffle(uint8_t *array, size_t n)
{
  if (n > 1)
  {
    size_t i;
    for (i = 0; i < n - 1; i++)
    {
      size_t j = i + rand() / (RAND_MAX / (n - i) + 1);
      int t = array[j];
      array[j] = array[i];
      array[i] = t;
    }
  }
}

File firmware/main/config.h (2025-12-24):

/*
   Copyright 2022 Adam McDaniel

   Licensed under the Apache License, Version 2.0 (the "License");
   you may not use this file except in compliance with the License.
   You may obtain a copy of the License at

       http://www.apache.org/licenses/LICENSE-2.0

   Unless required by applicable law or agreed to in writing, software
   distributed under the License is distributed on an "AS IS" BASIS,
   WITHOUT WARRANTIES OR CONDITIONS OF ANY KIND, either express or implied.
   See the License for the specific language governing permissions and
   limitations under the License.
*/

#ifndef CONFIG_H
#define CONFIG_H

// PCB Display Lights Layout
// Techncially the star is 16 LEDs wide and 15 LEDs tall, and is only 144 LEDs total.
// But we still need to treat the drawable area as a 16x16 square when the patterns are applied.
// See patterns.h
#define DISPLAY_LIGHTS_WIDTH  16
#define DISPLAY_LIGHTS_HEIGHT 16
#define DISPLAY_LIGHTS_TOTAL 144
#define DISPLAY_LIGHTS_TOTAL_AREA (DISPLAY_LIGHTS_WIDTH * DISPLAY_LIGHTS_HEIGHT)

// Gain must be 50 or less -- turning on all LEDs will overdraw power/overheat components!
#define DISPLAY_LIGHTS_MAX_GAIN      100
#define DISPLAY_LIGHTS_DEFAULT_GAIN  25

// Game of Life has a playgrid larger than the display area.  This allows for more
// complex designs that aren't constrainted to the 16x16 display framebuffer
#define GOL_GRID_HEIGHT   32
#define GOL_GRID_WIDTH    24
#define GOL_GRID_OFFSET_Y 8
#define GOL_GRID_OFFSET_X 4
#define GOL_GRID_TOTAL_AREA (GOL_GRID_HEIGHT * GOL_GRID_WIDTH)

// When the game isn't playing, the star sparkles
#define SPARKLE_MAX_LEDS     10
#define SPARKLE_MAX_STATE   100
#define SPARKLE_STEP          4
#define SPARKLE_STEPS        64
#define SPARKLE_RATE_MS      50

// Game logic defaults
#define GAME_START_LIVES      3
#define GAME_STAR_PERCENT    40
#define GAME_1UP_PERCENT     25
#define GAME_WARNING_PERCENT 25
#define GAME_DIE_PERCENT     50
#define GAME_ENDING_PERCENT  25

#if (CONFIG_IDF_TARGET_ESP32S2 || CONFIG_IDF_TARGET_ESP32S3)

// GPIO pin ports
#define PLAY_GAME_GPIO        1

#define ADC_LIGHT_CHANNEL    ADC1_CHANNEL_3 // GPIO 4

#define MUSIC_CHANNEL_1_GPIO 17
#define MUSIC_CHANNEL_2_GPIO 18
#define MUSIC_CHANNEL_3_GPIO 19
#define MUSIC_CHANNEL_4_GPIO 20
#define MUSIC_AMP_MUTE_GPIO  21

#define RGB_LED_GPIO         38

#define LIGHTS_LE_GPIO       33
#define LIGHTS_MISO_GPIO     34
#define LIGHTS_MOSI_GPIO     35
#define LIGHTS_SCLK_GPIO     36

#define EXT_LED1_GPIO        16
#define EXT_LED2_GPIO        15

#else

#error Only ESP32S2 and ESP32S3 configuration supported

#endif

/* Set EXTERN macro: */
#ifdef CONFIG_IMPORT
    #define CONFIG_EXTERN
#else
    #define CONFIG_EXTERN extern
#endif

#ifndef CONFIG_ESP_MAX_RETRY
#define CONFIG_ESP_MAX_RETRY 5
#endif
#ifndef CONFIG_ESP32_WIFI_STATIC_RX_BUFFER_NUM
#define CONFIG_ESP32_WIFI_STATIC_RX_BUFFER_NUM 32
#endif
#ifndef CONFIG_ESP32_WIFI_DYNAMIC_RX_BUFFER_NUM
#define CONFIG_ESP32_WIFI_DYNAMIC_RX_BUFFER_NUM 32
#endif
#ifndef CONFIG_ESP32_WIFI_TX_BUFFER_TYPE
#define CONFIG_ESP32_WIFI_TX_BUFFER_TYPE 1
#endif

#define CONFIG_FIRMWARE_URL_DEFAULT "https://starman.array.org"
#define CONFIG_FIRMWARE_URL_MAXLEN 50
CONFIG_EXTERN char config_firmware_service_url[CONFIG_FIRMWARE_URL_MAXLEN]
#ifdef CONFIG_IMPORT
= CONFIG_FIRMWARE_URL_DEFAULT
#endif
;

#define CONFIG_FIRMWARE_TRACK_STABLE   "stable"
#define CONFIG_FIRMWARE_TRACK_TESTING  "testing"
#define CONFIG_FIRMWARE_TRACK_UNSTABLE "unstable"

#define CONFIG_FIRMWARE_TRACK_DEFAULT CONFIG_FIRMWARE_TRACK_STABLE 
#define CONFIG_FIRMWARE_TRACK_MAXLEN 10
CONFIG_EXTERN char config_firmware_track[CONFIG_FIRMWARE_TRACK_MAXLEN]
#ifdef CONFIG_IMPORT
= CONFIG_FIRMWARE_TRACK_DEFAULT
#endif
;

CONFIG_EXTERN int8_t config_brightness
#ifdef CONFIG_IMPORT
= DISPLAY_LIGHTS_DEFAULT_GAIN
#endif
;

CONFIG_EXTERN uint8_t config_theme
#ifdef CONFIG_IMPORT
= 0
#endif
;

void config_set_firmware_track(char*);
void config_set_brightness(int8_t);
void config_set_theme(uint8_t);
void config_save(void);
void config_init(void);

#endif

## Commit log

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2018-12-16 Force a hardware reset after playback.
    For some reason, attachInterrupt() conflicts with pt.initchan()
    functions to the point after 2 or 3 music loops, the arduino hard-locks.
    As a workaround, execute a hardware reset after each loop. Not ideal
    but good enough: we don't need to track the state between runs.
    [arduino-starman.ino]
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2021-11-28 Fixed crash under some marquee patterns (buffer overflow); also removed button interrupt (was overkill, caused crashes)
    [arduino-starman.ino]
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2021-12-01 No need to reset after each cycle-- restart at stage 0 and randomize again
    [arduino-starman.ino]
2021-12-01 Strange bug where underwater crashes esp32 when debug logs are printed
    Need to figure out what\'s going on, but until then, just disable the logs!
    [Playtune.cpp]
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2021-12-12 PCB to handle the ESP32 and speaker components.
    [starman.kicad_pcb, starman.sch]
2021-12-12 Corrected resistor sizes, capacitor location, programming header.
    [starman.kicad_pcb]
2021-12-12 Minor adjustments to resistors and some placements
    [starman.kicad_pcb, starman.sch]
2021-12-12 Renamed pcb dir, added gerbers
    [starman-B_Cu.gbr, starman-B_Mask.gbr, starman-B_Paste.gbr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]
2021-12-14 Transition to standard ESP32 DevKit mounting
    [starman-B_Cu.gbr, starman-B_Mask.gbr, starman-B_Paste.gbr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]
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2021-12-14 Print the current level and lives on the ESP32-served webpage.
    After the button is pressed the new values are applied (level and
    lives) before the song is finished playing. Kind of odd when hitting
    refresh on the web page while the song is still playing. Kind of like
    foreshadowing the player's demise. Need to fix that!
    [arduino-starman.ino]
2021-12-18 Final placement modifications, off to PCB house!
    [starman-B_Cu.gbr, starman-B_Mask.gbr, starman-B_Paste.gbr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]
2021-12-26 Corrected pinouts to match PCB
    [arduino-starman.ino]
2021-12-26 Minor resistor updates to align with real build
    [starman.sch]
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2022-04-10 Begin complete PCB rewrite of starman for 2022
    [starman.kicad_pcb, starman.sch]
2022-04-10 Placements of components and things
    [starman.kicad_pcb, starman.sch]
2022-04-10 Switch to PCA9959 as LED PWM driver
    [starman.kicad_pcb, starman.sch]
2022-04-10 Route U2 and U3 LEDs
    [starman.kicad_pcb, starman.sch]
2022-04-13 Completed tracks to and from LED drivers
    [starman.kicad_pcb, starman.sch]
2022-04-14 Added mounting headers -- will move barrel jack and usb to daughter board
    [CUI_DEVICES_PJ-040-SMT-TR.step, starman.kicad_pcb, starman.sch]
2022-04-30 Transition to kicad v6
    [starman.kicad_pcb, starman.kicad_sch]
2022-04-30 Complete routing of all GPIO pins
    Also fixed paths to 3d components
    [starman.kicad_pcb, starman.kicad_sch]
2022-05-02 Added daughter board for power and buttons
    [starman.kicad_pcb, starman.kicad_sch]
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2022-05-24 Fixed DRC errors
    [starman.kicad_pcb, starman.kicad_sch]
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2022-08-01 Added some neat logos, fixed potentiometer
    [starman.kicad_pcb, starman.kicad_sch]
2022-08-01 Fixed U9 caps, and Y references
    [starman.kicad_pcb, starman.kicad_sch]
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2022-08-02 Adjusted soldermask clearance and edge mask to include breakaway tabs
    [starman.kicad_pcb]
2022-08-02 Clean up some +5V routes to be more balanced around D64 and D83
    [starman.kicad_pcb]
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2022-08-11 Properly define caps next to the 6 PCA9959 chips
    [starman.kicad_pcb, starman.kicad_sch]
2022-08-11 Fixed DRC, restored logos, fixed github url
    [starman.kicad_pcb, starman.kicad_sch]
2022-08-13 DRC corrections
    [starman.kicad_pcb]
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2022-08-23 Minor adjustments to align with stock available.
    - Adjusted J1 and J3 to be SMD headers (pin right)
    - Adjusted J6 and J7 to be sockets,
    - Restored R1 as part of U8
    - U9 is actually TO-252-3
    [starman.kicad_pcb, starman.kicad_sch]
2022-08-24 Add on headers for an external "Play" button
    [starman.kicad_pcb, starman.kicad_sch]
2022-08-27 Set mask clearance to 0.22mm
    [starman.kicad_pcb]
2022-08-29 Fixed the solderpad for U2..U7 according to match datasheet
    [starman.kicad_pcb, starman.kicad_sch]
2022-08-29 Run DRC, correct for spacing -- Fixed +5V to C11, D97, D110
    WARNING: there is a risk that C11 and D97 and D110 are not connected to
    +5V as this design already went for production. A bodge wire may be needed.
    At least its fixed for any future builds
    [starman.kicad_pcb]
2022-09-12 Reduce footprint and margins of OSRAM P47F LED
    Will be required to allow for space for the NXP chip replacement
    [starman.kicad_pcb, starman.kicad_sch]
2022-09-12 Fixed the orientation of J5, moved GND plane to top copper
    [starman.kicad_pcb, starman.kicad_sch]
2022-09-15 Completely replace NXP with LED1642GWTTR
    [starman.kicad_pcb, starman.kicad_sch]
2022-09-15 Additional routing around new LED chips, cleaned up DRC errors and warnings
    [starman.kicad_pcb, starman.kicad_sch]
2022-09-15 Move from NCP59301 to AP1084
    Cheaper and provides 5V 5A
    [starman.kicad_pcb, starman.kicad_sch]
2022-09-15 Moved caps and rs from ext to onboard star to make room for potential opamp
    [starman.kicad_pcb, starman.kicad_sch]
2022-09-17 Change U11 AP1084 to AZ1084CS2-ADJ (due to stock)
    [starman.kicad_pcb, starman.kicad_sch]
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2022-09-17 Updated BOM, footprints with actual part numbers based on stock
    [starman.kicad_pcb, starman.kicad_sch]
2022-09-18 Redo SPI traces according to best practices document
    https://www.st.com/resource/en/application_note/an4374-the-led1642gw-and-aled1642gw-startup-guide-stmicroelectronics.pdf
    [starman.kicad_pcb, starman.kicad_sch]
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2022-09-18 Fixed footprints for C20..28, added polarities to silkscreen
    [starman.kicad_pcb, starman.kicad_sch]
2022-09-19 Added placeholders for low-pass filters for SCLK, LE pins -- just incase of poor signal quality
    Populate with 100Ω and 150pF, respectively
    [starman.kicad_pcb, starman.kicad_sch]
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2022-09-21 Replace LM386 with IS31AP4991
    [starman.kicad_pcb, starman.kicad_sch]
2022-09-21 Add on a power switch and status light
    [starman.kicad_pcb, starman.kicad_sch]
2022-09-21 Fixed some routing
    [starman.kicad_pcb]
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2022-09-26 Scrap the band-pass filter; get the proper 3d model for the speaker candidate
    Tests showed it wasn't necessary
    [SMS-1508MS-HT-R.step, starman.kicad_pcb, starman.kicad_sch]
2022-09-27 Added on an optional mosfet and power switch
    [starman.kicad_pcb, starman.kicad_sch]
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2022-09-29 Cleaned up speaker footprint, some routing, and some caps
    [expansion.kicad_sch, starman.kicad_pcb, starman.kicad_sch]
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2022-09-29 Final run fixing ERC and DRC warnings
    [starman-B_Cu.gbr, starman-B_Mask.gbr, starman-B_Paste.gbr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]
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2022-10-06 Lowered amp's pulldown resistor from 10k to 1k
    [expansion.kicad_sch, starman.kicad_pcb, starman.kicad_sch]
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2022-10-06 Move R8..R16, C8..C16 closer to U2..U10
    Also cleaned up some LED routing to remove redundant vias
    [starman.kicad_pcb, starman.kicad_sch]
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2022-10-07 Updates to high-speed SCLK and LE lines
    Hopefully to minimize interference and cross talk
    [starman.kicad_pcb]
2022-10-07 Refreshed BOM and Gerbers for upcoming production run.
    [starman-B_Cu.gbr, starman-B_Mask.gbr, starman-B_Paste.gbr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]
2022-10-08 Created a 3d-printed mount to better secure the star to the top of the tree
    [mount.scad, mount.stl]
2022-10-08 Convert BOM from HTML to CSV
    The ibom plugin is cool but it's pretty bloated
    [bom.csv]
2022-10-09 Adjust and verify dimensions for the mount to the physical 2.0 PCBA
    [mount.scad, mount.stl]
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2022-10-17 Standardized on the dimensional measurement thickness
    Has no effect on the PCB design which was sent to production
    [starman.kicad_pcb]
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2022-10-18 Debug a crash occuring in the sparkle task
    [buttons.c, config.h, led1642gw.c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]
2022-10-18 Move sound channels 1,2 output from GPIO17,18 to GPIO15,16
    Possible issue with ESP32-S3's emitting PWM signals on GPIO17 and GPIO18
    [starman.kicad_pcb, starman.kicad_sch]
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2022-10-22 Revert "Move sound channels 1,2 output from GPIO17,18 to GPIO15,16"
    This reverts commit e08c3b28f5e48cf3460c7e3369e7ae4fbe1a676e.
    Got GPIO 17 and 18 to work by initializing them as an OUTPUT channel.
    No PCB change necessary!
    [starman.kicad_pcb, starman.kicad_sch]
2022-10-23 Identify that input power is 5-7V, max 2A
    Seems if you plug 12V in, U11's Vref changes and the assumed 5V output
    turns out to be 8V, and it fries the amplifier. Oops.
    Until U11 can be changed to a fixed LDO, specify that 5-7V is required.
    [starman.kicad_pcb]
2022-10-23 Fix the look-up table between the level-shift array position to the physical LED position
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2022-10-23 Fix the pattern invert and scroll functions
    [patterns.c]
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2022-10-24 Put a cap on the LED gain at 50.
    Exceeding that could overheat the board when all lights are on full power
    [config.h, led1642gw.c]
2022-10-24 Correct pattern rotation/scrolling -- simplify the checkered pattern too
    [patterns.c]
2022-10-24 Fixed mixing up data intended for D4, D15, D36, and D40
    [led1642gw.c, patterns.c]
2022-10-28 Fixed an issue where the sparkle spontaneously stops for ~600 ticks
    [sparkle.c]
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2022-10-30 Import the Wifi/Network/OTA/Storage modules from my Caliper project
    [partitions.csv]
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2022-10-31 Since we cannot use RMT, instead attempt to bitbang the protocol.
    Note, the status light remains disabled until a fix in the PCB is
    applied. See next commit.
    [status.c]
2022-10-31 Reroute and fillet GPIO 38 into a straighter net
    Hopefully this will resolve communication issues to the WS2812B at D145
    [starman.kicad_pcb]
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2022-11-07 Expand the mount base to better support the star
    [mount.scad, mount.stl]
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2022-11-09 Add a Semaphore mutex lock when updating the display
    Prevents colliding LED1642 data when two objects are updating the
    display at a different interval.
    [display.c, patterns.c]
2022-11-12 Revert "Use local instance of firmware server for testing"
    This reverts commit 7f949fbbcf99c1bf262ee8d2536232a2103268e7.
    [config.h]
2022-11-12 Bump application partition sizes to 2680K
    This takes advantage of the 8MB available on ESP32-S3 on all three
    parittions: factory and two OTA.
    [partitions.csv]
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2022-11-13 Simple shell script for uploading firmware images to Google Storage bucket
    This makes the image accesible to download from the server at:
    https://starman.array.org/{stable,testing,unstable}
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2022-11-18 Added a notch in the mount to avoid colliding with height of U11 LDO
    [mount.scad, mount.stl]
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2022-11-21 Resolve warning messages of unused vars/funcs
    [display.c, music.c]
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2022-11-23 Get/set firmware update track
    Firmware can follow either the stable, testing, or unstable tracks
    [config.h]
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2022-11-27 Create a GET /reset endpoint to trigger a device reset via HTTP REST
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2022-11-30 Start playing on the release of play button, not down-press.
    [buttons.c]
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2022-12-01 Revert "Start playing on the release of play button, not down-press."
    This reverts commit 95783a92dc73177bd57c60f3d6cca442940b7592.
    [buttons.c]
2022-12-01 Fix an issue where note duration is mis-interpreted as the end of the song (0xF0)
    [music.c]
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2022-12-10 Additional logging to ensure to correct theme's game logic is started
    [game.c]
2022-12-11 Clean up LOZ music -- cut for length and correct melodic errors
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2022-12-23 Replace malloc() with calloc()
    [music.c]
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2023-12-04 Add logic to rotate through the themes though button short/long presses
    - Long-press to go into theme-select mode
    - Short-press to change themes
    - Long-press to save the theme and return to game mode
    [buttons.c, music.c]
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2023-12-12 Adjust the mount to fit more snugly between the starman PCBs
    [mount.scad, mount.stl]
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2024-04-21 Bump the variable resistor to 20k, update the schematics, BOM for printing
    Also marked C33 & D145 as NC (never could get it to work). It should
    be replaced by a proper multi-lead RGB LED
    [bom.csv, expansion.kicad_sch, starman.kicad_sch]
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2024-04-30 Created a 3d printed stencil mount help with spreading solder paste
    [pcb.scad, stencil.scad, stencil.stl]
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2026-09-28 Upgraded project to KiCad 10, updated the BOM, schematic PDF
    [bom.csv, expansion.kicad_sch, starman.kicad_pcb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]

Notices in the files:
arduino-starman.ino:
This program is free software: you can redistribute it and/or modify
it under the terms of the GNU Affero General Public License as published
